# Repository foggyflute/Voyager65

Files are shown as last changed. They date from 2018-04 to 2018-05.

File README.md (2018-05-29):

# Voyager65
Cutting-edge 65% keyboard PCB

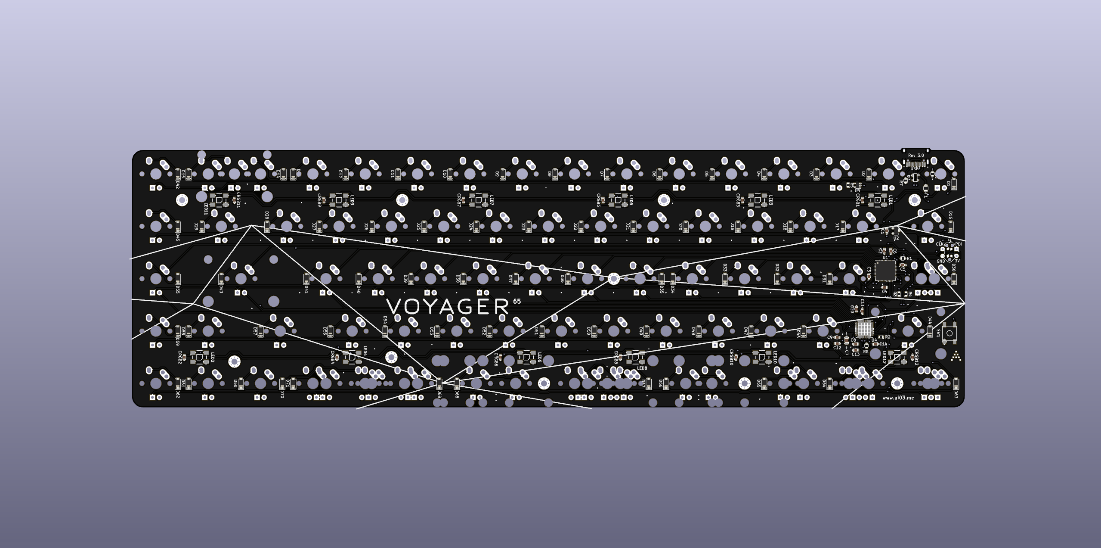
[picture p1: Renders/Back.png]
Frontside Render

[Supported Layouts](http://www.keyboard-layout-editor.com/#/gists/98784f0271c0b4e29edec77185eb883a)

## Features
* Full individual-controllable backlighting via ISSI IS31FL3733
* Atxmega32a4u controller for Keyplus firmware usage
* Overcurrent and ESD protection, along with physically durable design
* Type-C USB connector
* RGB underglow with WS2812B/C chips
* Easy programming via TC2030-IDC header
* Alps and MX compatibility
* **Completely** open-source: All the files you need to make a keyboard with it, design a case/plate for it, or even produce a batch of PCBs for your next GB, are all to be available free.
* The latest technology, some of which is untested or unstable.

## Status
* Prototypes created
* Main switch matrix confirmed functional
* LEDs still untested

## Variants
* Voyager65: This branch. All the features.
* [V65LE](https://github.com/ai03-2725/Voyager65/tree/V65LE): A low-cost, stencil-less solderable variant. Same switch matrix, but with all LEDs removed.
* [V65AE](https://github.com/ai03-2725/Voyager65/tree/V65AE): Alps-specific variant.

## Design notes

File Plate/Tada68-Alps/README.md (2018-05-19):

#WARNING

Alps switches are wide! This means a regular M2 screw WILL NOT FIT between two keys, i.e. between G and H!

To get around this, find M2 screws with head diameters smaller than 3.45mm.

Also, the screwdriver for securing the screw must be less than 1.7mm diameter.

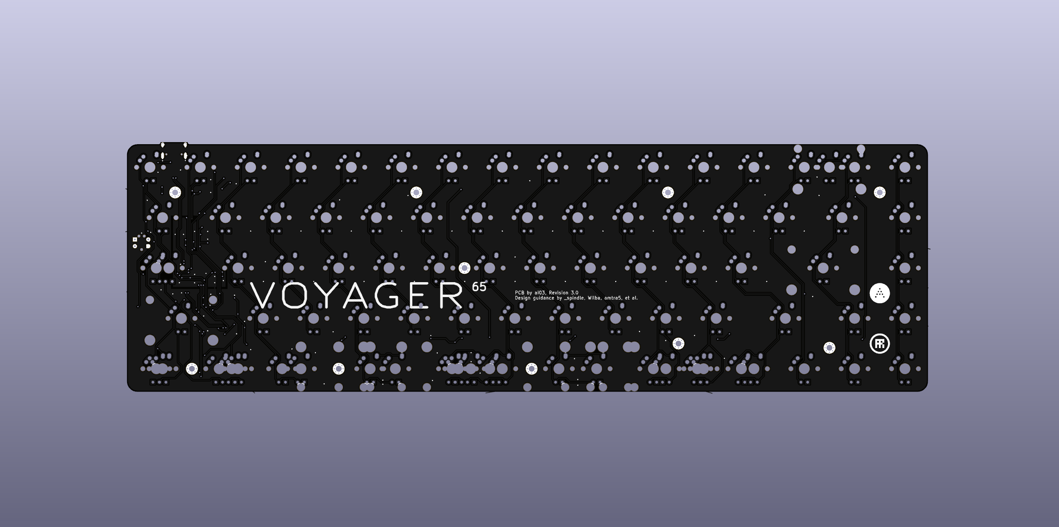
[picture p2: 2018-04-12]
Renders/Front.png

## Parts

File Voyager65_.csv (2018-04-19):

Component | Description | Part | References | Value | Footprint | Quantity Per PCB | Voltage | Wattage | Current Max | Current Hold | Current Trip | Datasheet
1 | Unpolarized capacitor, Ceramic | C_Small | C2 C3 C4 C5 C8 C9 C10 CRGB1 CRGB2 CRGB3 CRGB4 CRGB5 CRGB6 CRGB7 CRGB8 CRGB9 CRGB10 CRGB11 CRGB12 | 0.1u | C_0603 | 19 | 25V
2 | Unpolarized capacitor, Ceramic | C_Small | C11 C12 C13 C14 | 0.47u | C_0603 | 4 | 25V
3 | Unpolarized capacitor, Ceramic | C_Small | C6 | 10u | C_0603 | 1 | 25V
4 | Unpolarized capacitor, Ceramic | C_Small | C1 | 1u | C_0603 | 1 | 25V
5 | Polarised capacitor, Tantalum | CP1_Small | C7 | 22u | C_0805 | 1 | 10V
6 | Diode, General Purpose | D_Small | D1 D2 D3 D4 D5 D6 D7 D8 D9 D10 D11 D12 D13 D14 D15 D16 D17 D18 D19 D20 D21 D22 D23 D24 D25 D26 D27 D28 D29 D30 D31 D32 D33 D34 D35 D36 D37 D38 D39 D40 D41 D42 D43 D44 D45 D46 D47 D48 D49 D50 D51 D52 D53 D54 D55 D56 D57 D58 D59 D60 D61 D62 D63 D64 D65 D66 D67 D68 D69 D70 D71 | D_Small | D_SOD-123 | 71 | 50V or higher |  | 1A
7 | Resettable Fuse (Polyfuse) | Polyfuse_Small | F1 | 500mA | R_0805 | 1 | 10V or higher |  |  | 500mA | 1A
8 | RGB LED with integrated controller | WS2812B | LED1 LED2 LED3 LED4 LED5 LED6 LED7 LED8 LED9 LED10 LED11 LED12 | WS2812B | WS2812B | 12
9 | Resistor, generic | R_Small | R2 | 100k | R_0603 | 1 |  | 1/10W or higher
10 | Resistor, generic | R_Small | R1 | 10k | R_0603 | 1 |  | 1/10W or higher
11 | Resistor, generic | R_Small | R3 R4 | 1k | R_0603 | 2 |  | 1/10W or higher
12 | Resistor, generic | R_Small | R8 | 20k | R_0603 | 1 |  | 1/10W or higher
13 | Resistor, generic | R_Small | R6 R7 | 5.1k | R_0603 | 2 |  | 1/10W or higher
14 | Resistor, generic | R_Small | R5 | 470 | R_0603 | 1 |  | 1/10W or higher
15 | Push switch, 5.2mm wide, 1.5mm tall | SW_PUSH | SW1 | SW_PUSH | SKQG-1155865 | 1
16 | Non-Inverting IC Buffer 74LVC1G34 | 74LVC1G34 | U5 | 74LVC1G34 | SOT-353_SC-70-5 | 1 | 5.5V |  |  |  |  | https://www.diodes.com/assets/Datasheets/74LVC1G34.pdf
17 | TQFP44, 16k Flash, 4k Boot, 2k SRAM, 1k EEPROM, JTAG, USB | ATXMEGA32A4U-AU | U1 | ATXMEGA32A4U-MH | QFN-44-1EP_7x7mm_Pitch0.5mm | 1 |  |  |  |  |  | http://www.atmel.com/Images/Atmel-8387-8-and16-bit-AVR-Microcontroller-XMEGA-A4U_Datasheet.pdf
18 | LED Matrix Driver IS31FL3733 | IS31FL3733 | U4 | IS31FL3733-QFLS4-TR | QFN-48-1EP_6x6mm_Pitch0.4mm | 1 |  |  |  |  |  | http://www.issi.com/WW/pdf/31FL3733.pdf
19 | 250mA Low Quiscent Current LDO, 3.0V output, SOT-23 | MCP1700-3002E_SOT23 | U2 | MCP1700T-3002E/TT | SOT-23 | 1 |  |  |  |  |  | http://ww1.microchip.com/downloads/en/DeviceDoc/20001826C.pdf
20 | ESD Protection Diode IC | PRTR5V0U2X | U3 | PRTR5V0U2X | SOT143B | 1 |  |  |  |  |  | https://assets.nexperia.com/documents/data-sheet/PRTR5V0U2X.pdf
21 | USB Type-C Connector HRO-TYPE-C-31-M-12 | HRO-TYPE-C-31-M-12 | USB1 | HRO-TYPE-C-31-M-12 | HRO-TYPE-C-31-M-12 | 1 |  |  |  |  |  | https://datasheet.lcsc.com/szlcsc/TYPE-C-31-M-12-Female-head-socket-16P-SMD_C165948.pdf
Component Groups: | 21
Component Count: | 125
Fitted Components: | 125
Number of PCBs: | 1
Total components: | 125
Schematic Version:
Schematic Date:
BoM Date: | 4/17/2018 20:48
Schematic Source: | C:/Users/Ryota/Documents/GitHub/Voyager65/Voyager65.sch
KiCad Version: | Eeschema 4.0.7

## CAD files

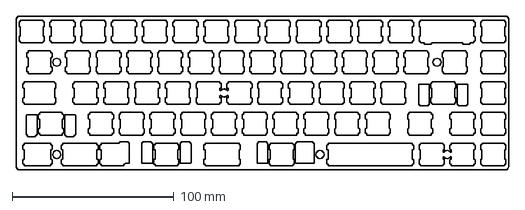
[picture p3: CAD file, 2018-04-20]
Plate/Source/Tada68-MX.dxf
304.8 x 95.3 mm

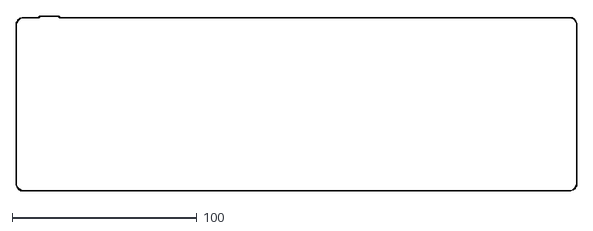
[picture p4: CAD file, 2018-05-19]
DXF/Voyager65-Edge.Cuts.dxf
303.4 x 94.6

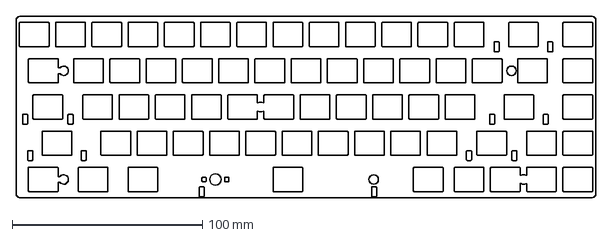
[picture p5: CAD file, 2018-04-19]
Plate/Source/Tada68-Alps.dxf
304.8 x 95.3 mm

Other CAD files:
DXF/Voyager65-F.Fab.dxf
DXF/Voyager65-B.Mask.dxf
DXF/Voyager65-B.Paste.dxf
DXF/Voyager65-B.SilkS.dxf
DXF/Voyager65-F.Mask.dxf
DXF/Voyager65-F.Paste.dxf
DXF/Voyager65-F.SilkS.dxf

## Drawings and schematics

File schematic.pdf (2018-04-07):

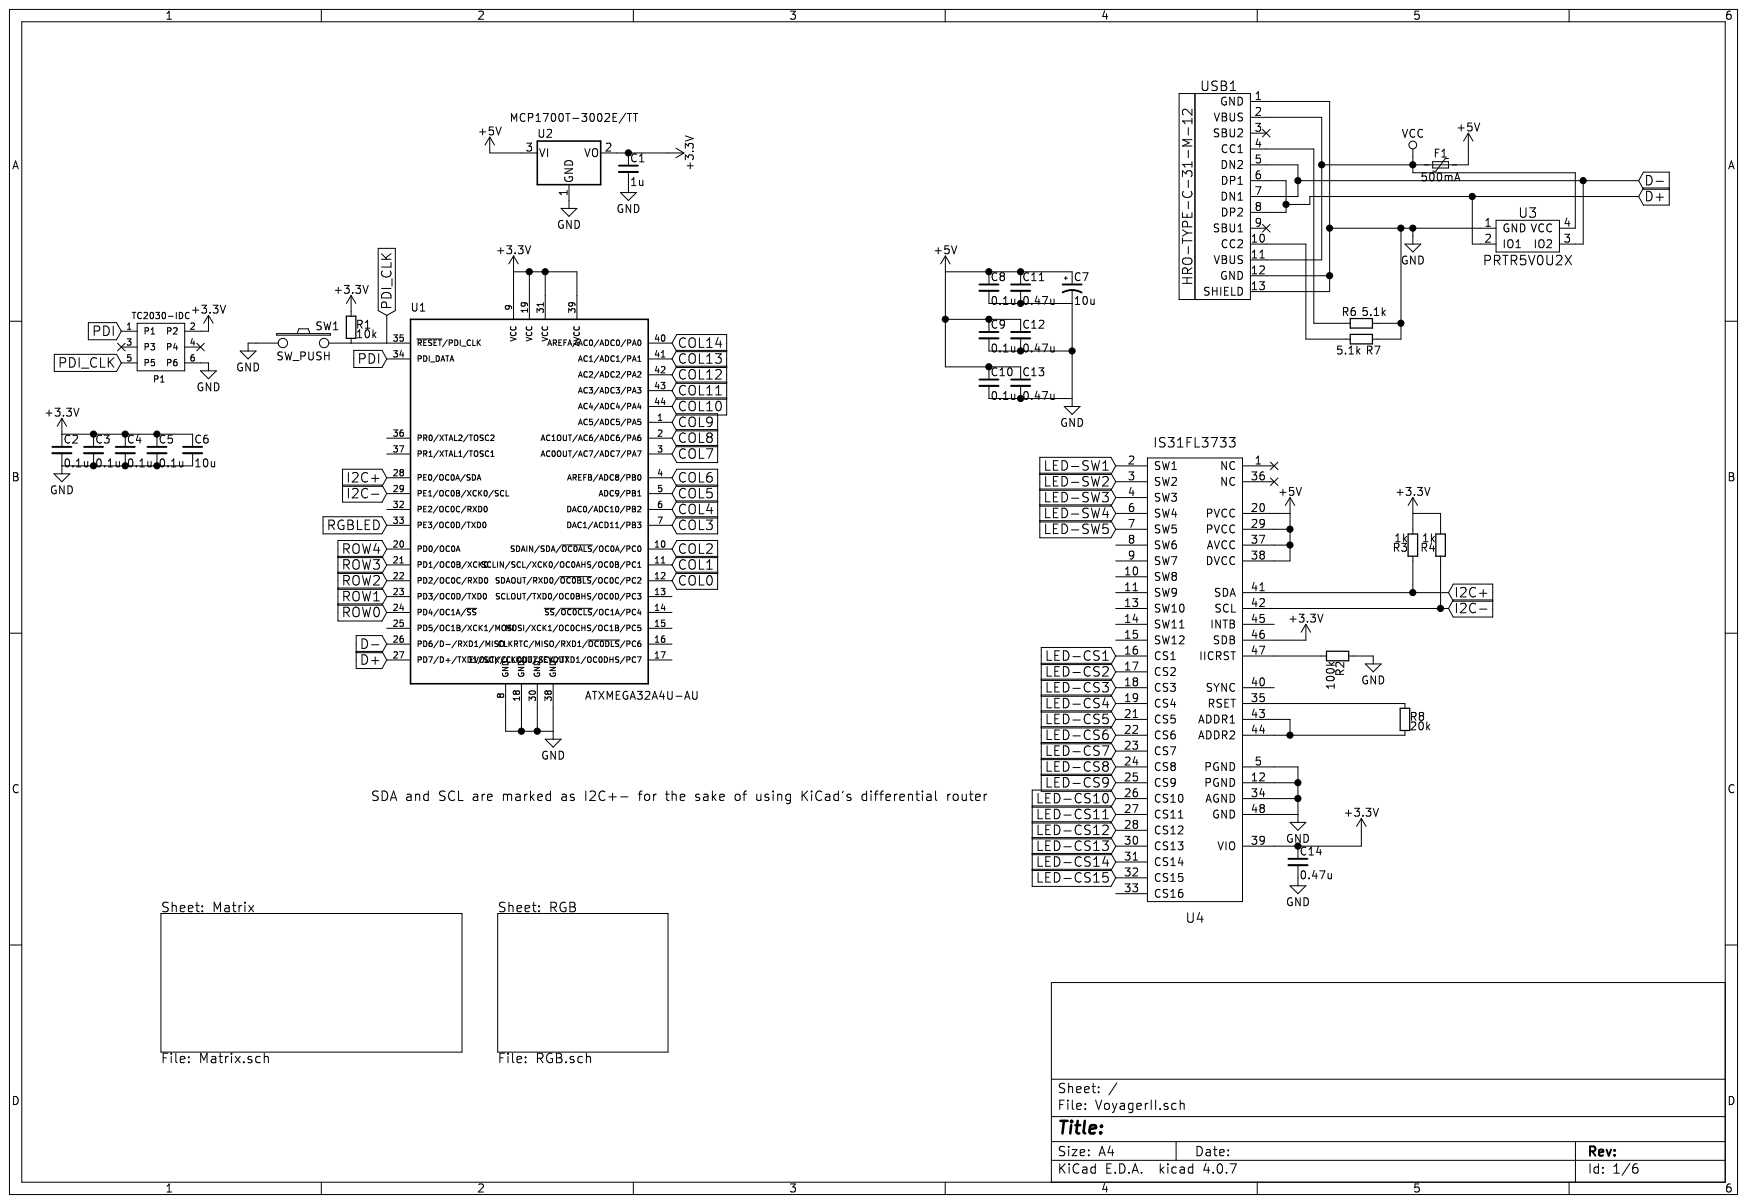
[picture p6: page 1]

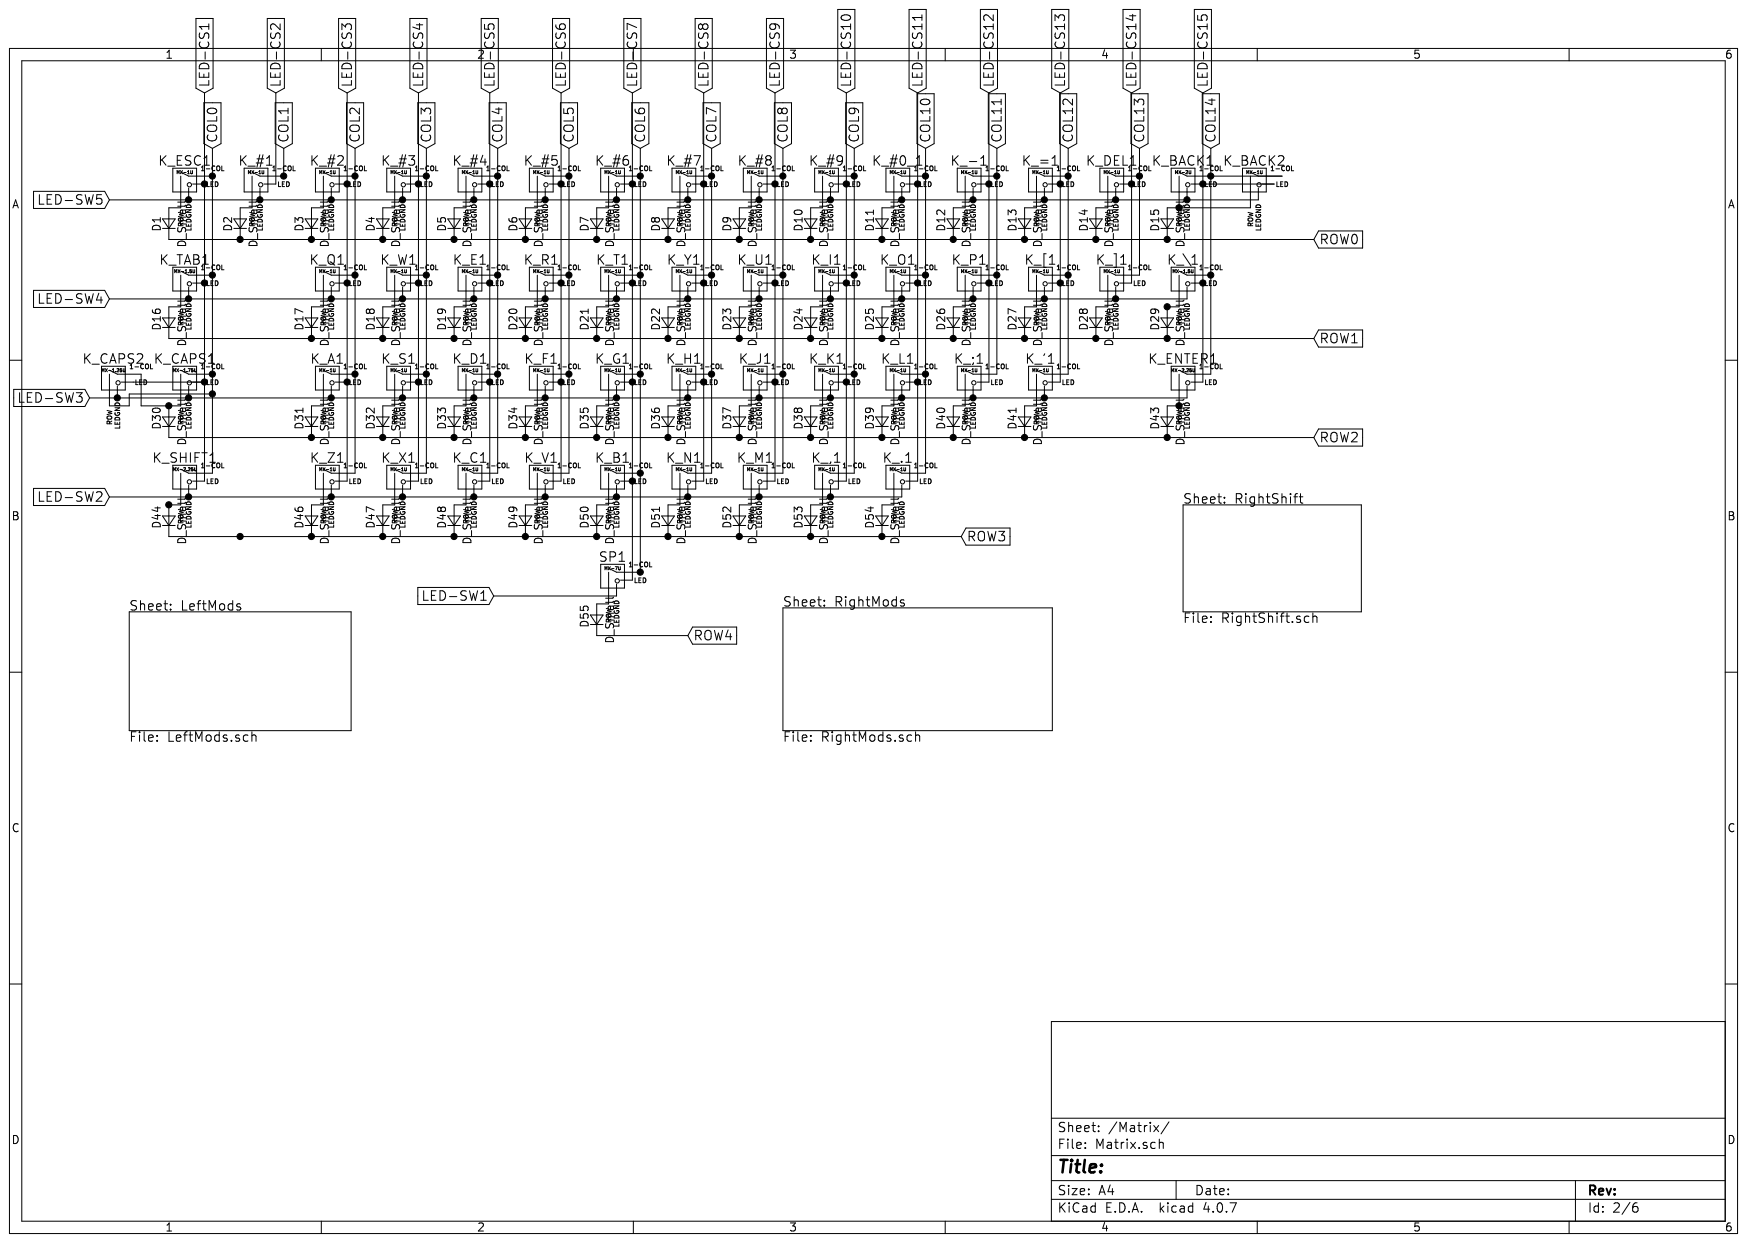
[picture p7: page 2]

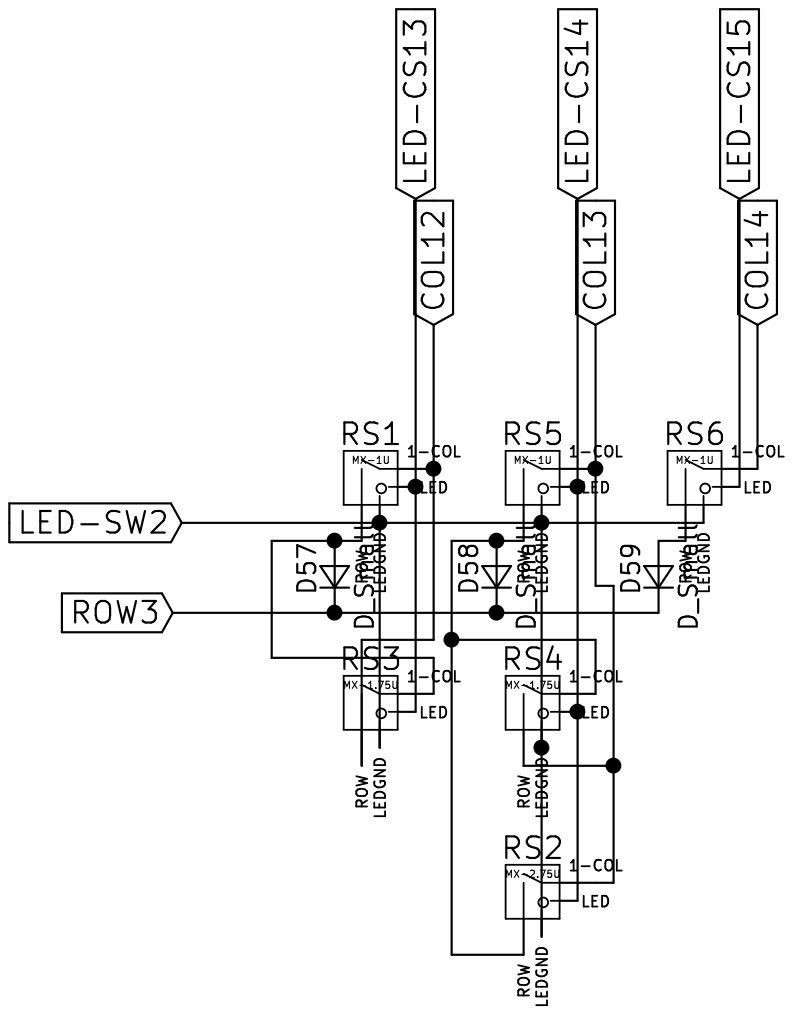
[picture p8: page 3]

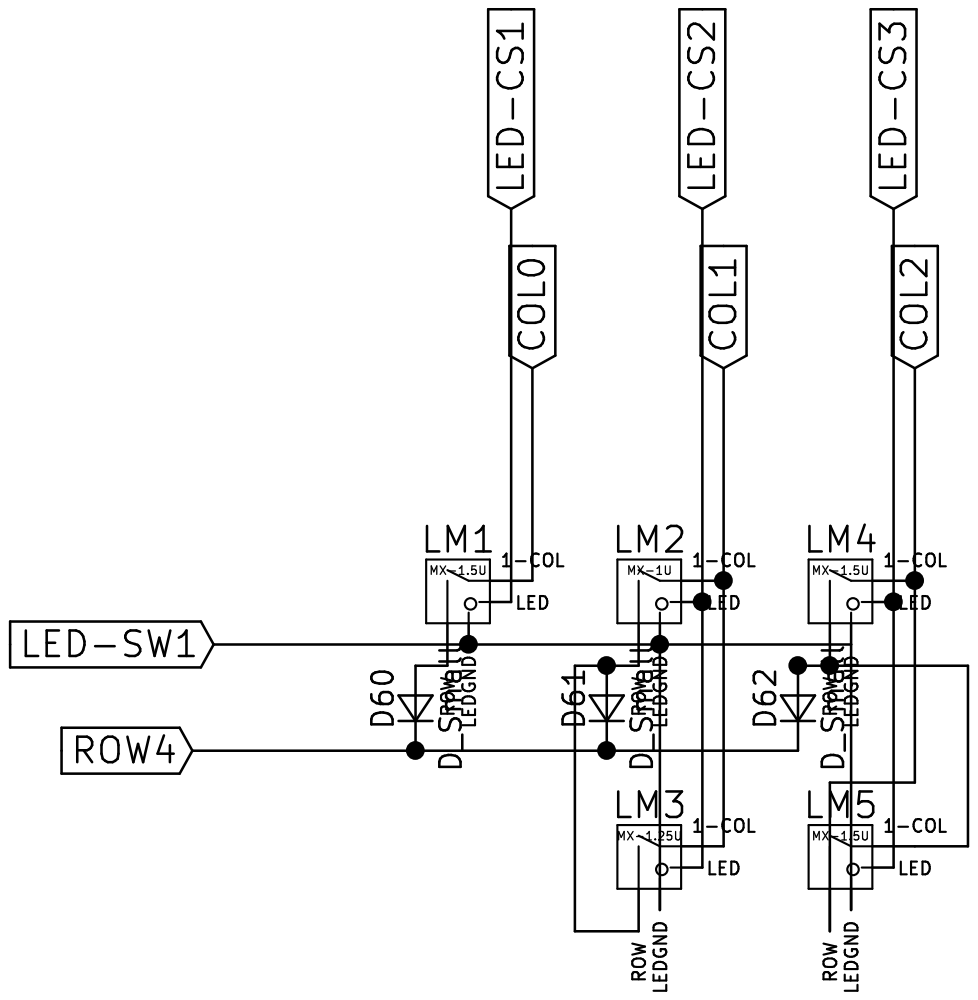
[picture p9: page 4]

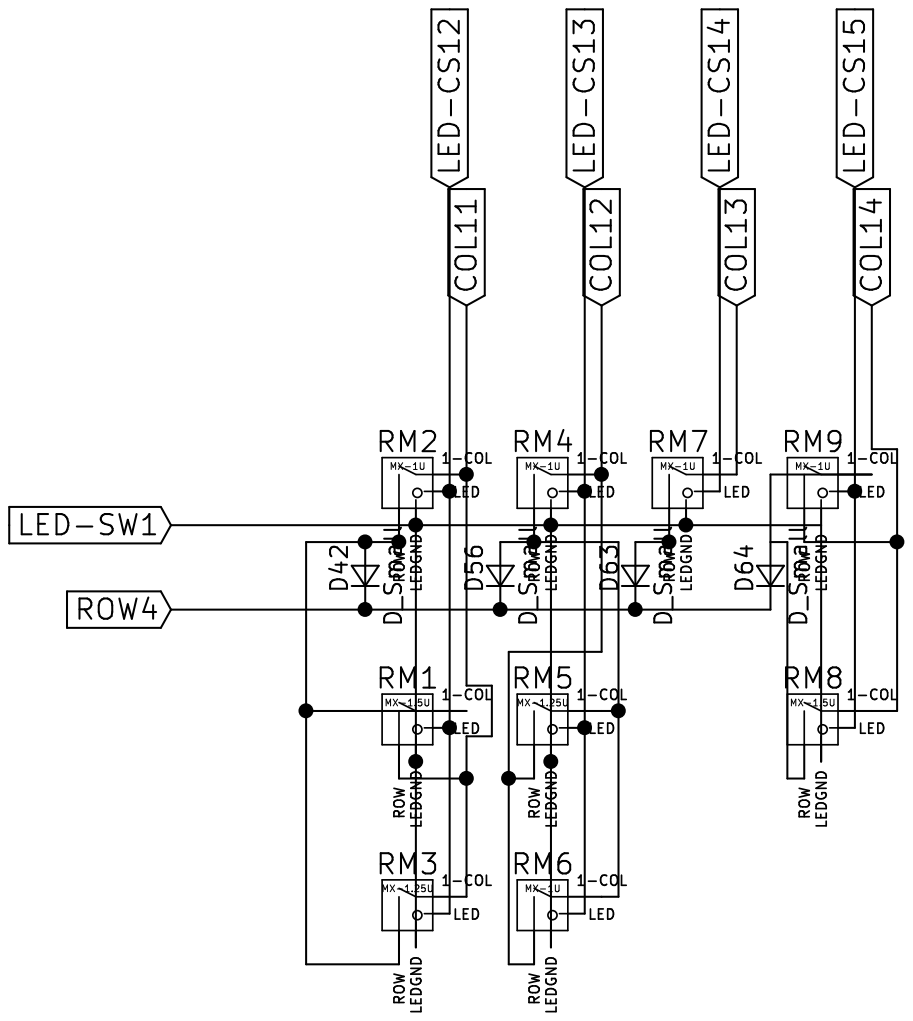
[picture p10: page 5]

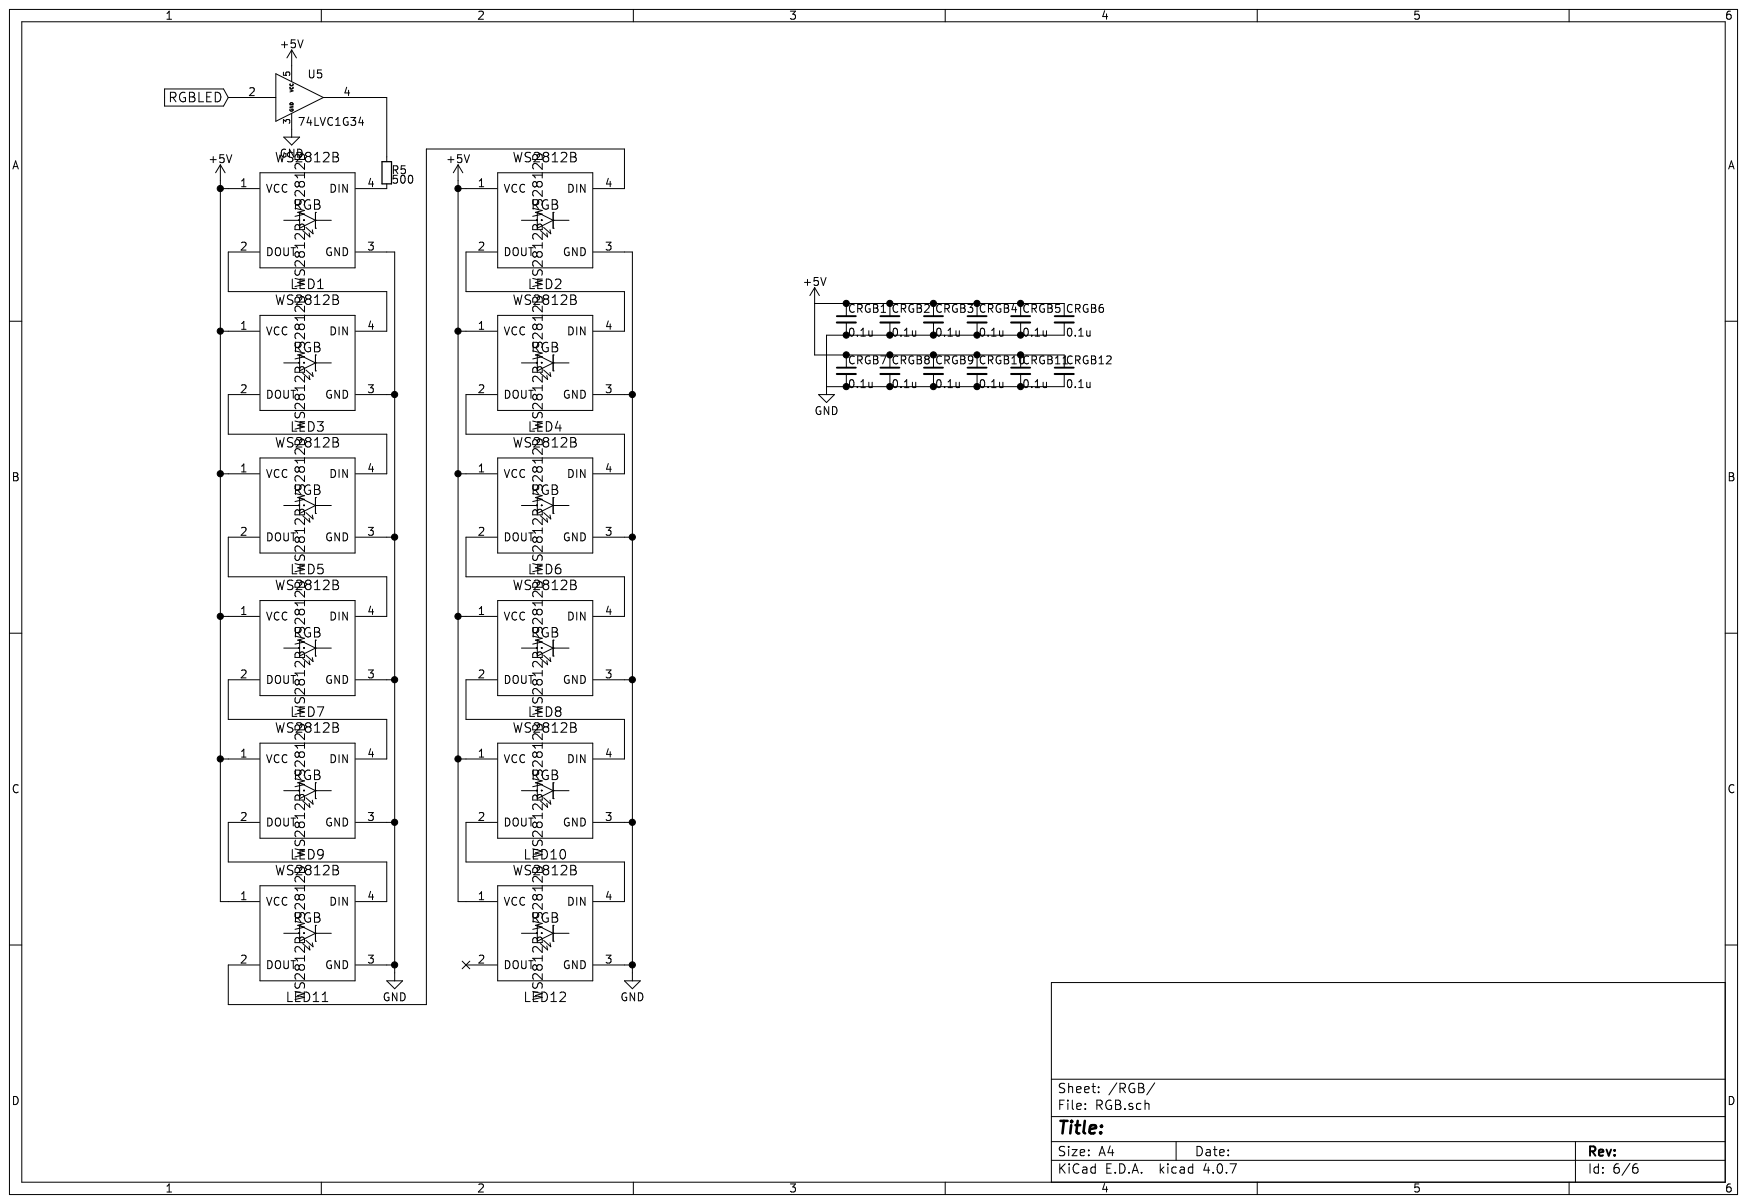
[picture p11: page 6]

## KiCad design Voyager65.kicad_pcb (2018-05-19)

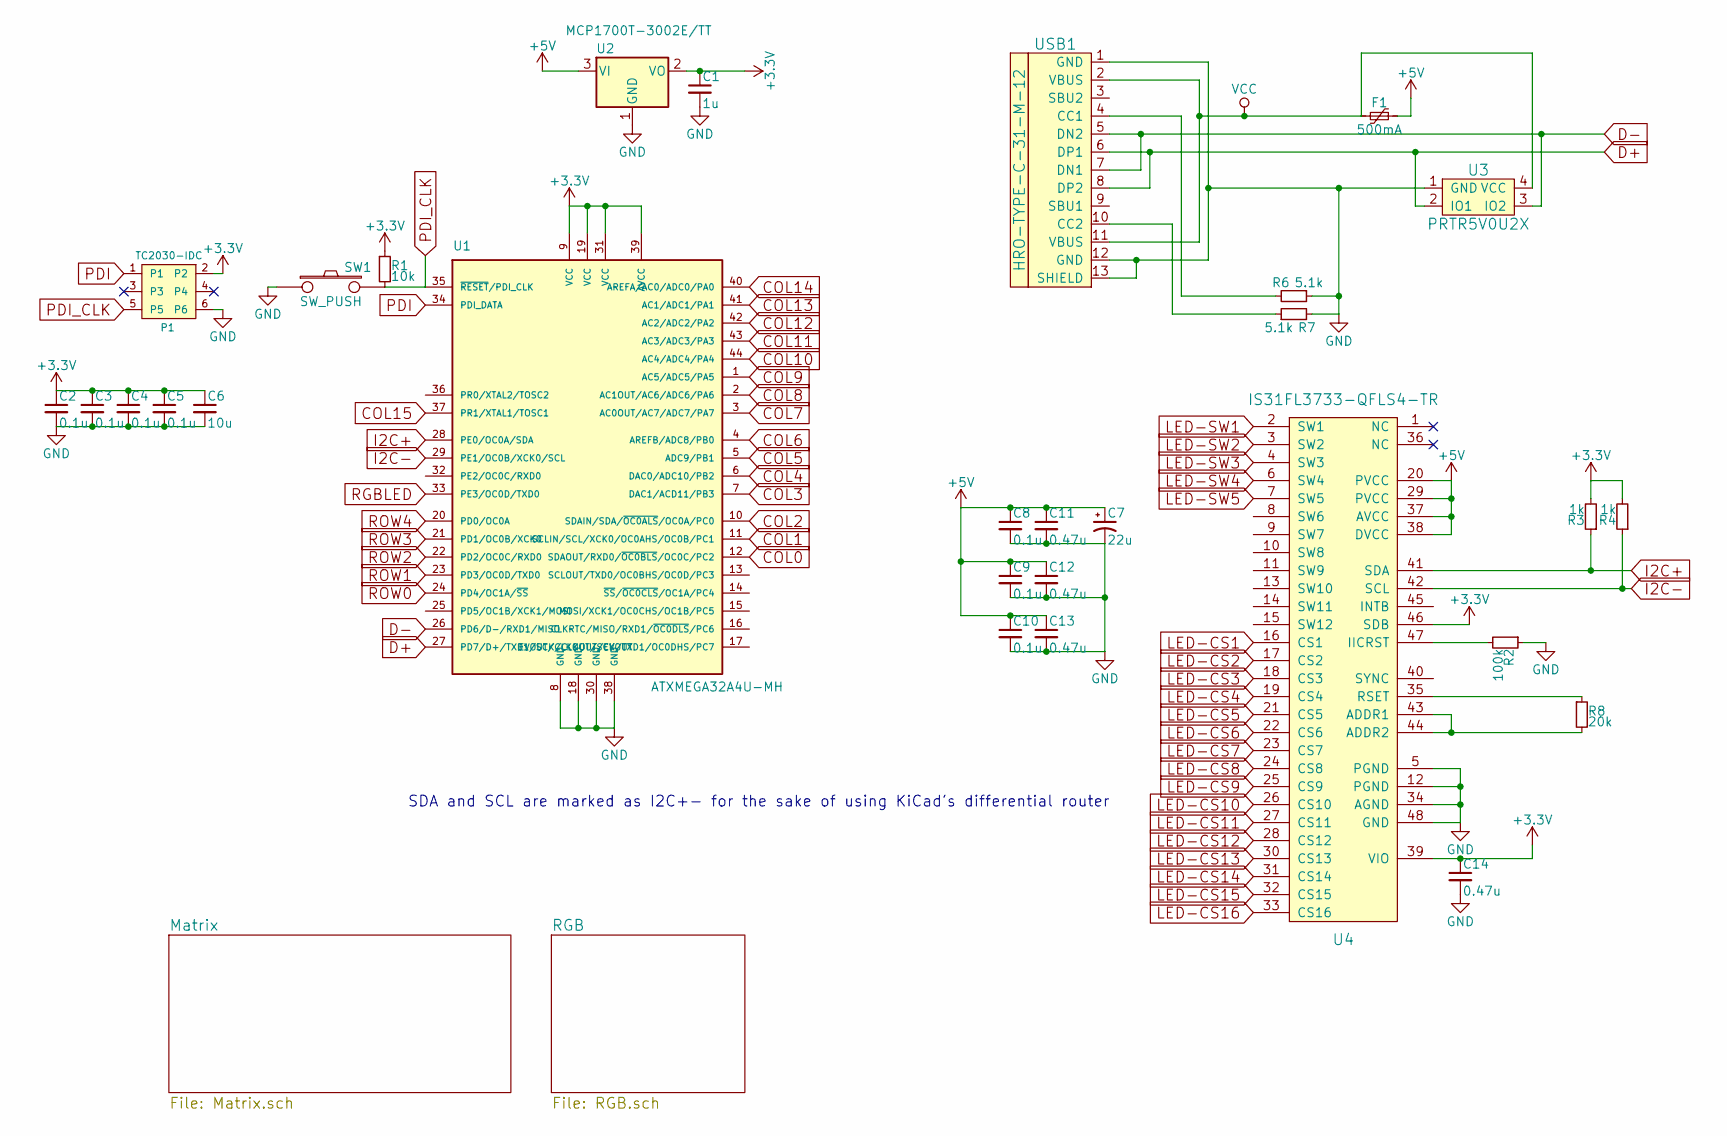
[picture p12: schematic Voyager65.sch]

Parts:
C1: 1u; C_0603
C2, C3, C4, C5, C8, C9, C10: 0.1u; C_0603
C6: 10u; C_0603
C7: 22u; C_0805; Voltage 10V
C11, C12, C13, C14: 0.47u; C_0603
F1: 500mA; R_0805
P1: TC2030-IDC; TC2030-NL_SMALL_AND_IDC_PDI
R1: 10k; R_0603
R2: 100k; R_0603
R3, R4: 1k; R_0603
R6, R7: 5.1k; R_0603
R8: 20k; R_0603
SW1: SW_PUSH; SKQG-1155865
U1: ATXMEGA32A4U-MH; QFN-44-1EP_7x7mm_Pitch0.5mm
U2: MCP1700T-3002E/TT; SOT-23
U3: PRTR5V0U2X; SOT143B
U4: IS31FL3733-QFLS4-TR; QFN-48-1EP_6x6mm_Pitch0.4mm
USB1: HRO-TYPE-C-31-M-12

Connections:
+3V3: C1.1, C2.1, C3.1, C4.1, C5.1, C6.1, C14.1, P1.2, R1.1, R3.2, R4.2, U1.9 (VCC), U1.19 (VCC), U1.31 (VCC), U1.39 (AVCC), U2.2 (VO), U4.39 (VIO), U4.46 (SDB)
+5V: C7.1, C8.1, C9.1, C10.1, C11.1, C12.1, C13.1, F1.1, U2.3 (VI), U4.20 (PVCC), U4.29 (PVCC), U4.37 (AVCC), U4.38 (DVCC); also elsewhere on the board
COL0: U1.12 (SDAOUT/RXD0/~OC0BLS~/OC0C/PC2); also elsewhere on the board
COL1: U1.11 (SCLIN/SCL/XCK0/OC0AHS/OC0B/PC1); also elsewhere on the board
COL2: U1.10 (SDAIN/SDA/~OC0ALS~/OC0A/PC0); also elsewhere on the board
COL3: U1.7 (DAC1/ACD11/PB3); also elsewhere on the board
COL4: U1.6 (DAC0/ADC10/PB2); also elsewhere on the board
COL5: U1.5 (ADC9/PB1); also elsewhere on the board
COL6: U1.4 (AREFB/ADC8/PB0); also elsewhere on the board
COL7: U1.3 (AC0OUT/AC7/ADC7/PA7); also elsewhere on the board
COL8: U1.2 (AC1OUT/AC6/ADC6/PA6); also elsewhere on the board
COL9: U1.1 (AC5/ADC5/PA5); also elsewhere on the board
COL10: U1.44 (AC4/ADC4/PA4); also elsewhere on the board
COL11: U1.43 (AC3/ADC3/PA3); also elsewhere on the board
COL12: U1.42 (AC2/ADC2/PA2); also elsewhere on the board
COL13: U1.41 (AC1/ADC1/PA1); also elsewhere on the board
COL14: U1.40 (AREFA/AC0/ADC0/PA0); also elsewhere on the board
COL15: U1.37 (PR1/XTAL1/TOSC1); also elsewhere on the board
D+: U1.27 (PD7/D+/TXD1/SCK/CLKOUT/EVOUT), U3.2 (IO1), USB1.6 (DP1), USB1.8 (DP2)
D-: U1.26 (PD6/D-/RXD1/MISO), U3.3 (IO2), USB1.5 (DN2), USB1.7 (DN1)
GND: C1.2, C2.2, C3.2, C4.2, C5.2, C6.2, C7.2, C8.2, C9.2, C10.2, C11.2, C12.2, C13.2, C14.2, P1.6, R2.1, R6.1, R7.2, SW1.1, U1.8 (GND), U1.18 (GND), U1.30 (GND), U1.38 (GND), U2.1 (GND), U3.1 (GND), U4.5 (PGND), U4.12 (PGND), U4.34 (AGND), U4.48 (GND), USB1.1 (GND), USB1.12 (GND), USB1.13 (SHIELD); also elsewhere on the board
I2C+: R3.1, U1.28 (PE0/OC0A/SDA), U4.41 (SDA)
I2C-: R4.1, U1.29 (PE1/OC0B/XCK0/SCL), U4.42 (SCL)
LED-CS1: U4.16 (CS1); also elsewhere on the board
LED-CS2: U4.17 (CS2); also elsewhere on the board
LED-CS3: U4.18 (CS3); also elsewhere on the board
LED-CS4: U4.19 (CS4); also elsewhere on the board
LED-CS5: U4.21 (CS5); also elsewhere on the board
LED-CS6: U4.22 (CS6); also elsewhere on the board
LED-CS7: U4.23 (CS7); also elsewhere on the board
LED-CS8: U4.24 (CS8); also elsewhere on the board
LED-CS9: U4.25 (CS9); also elsewhere on the board
LED-CS10: U4.26 (CS10); also elsewhere on the board
LED-CS11: U4.27 (CS11); also elsewhere on the board
LED-CS12: U4.28 (CS12); also elsewhere on the board
LED-CS13: U4.30 (CS13); also elsewhere on the board
LED-CS14: U4.31 (CS14); also elsewhere on the board
LED-CS15: U4.32 (CS15); also elsewhere on the board
LED-CS16: U4.33 (CS16); also elsewhere on the board
LED-SW1: U4.2 (SW1); also elsewhere on the board
LED-SW2: U4.3 (SW2); also elsewhere on the board
LED-SW3: U4.4 (SW3); also elsewhere on the board
LED-SW4: U4.6 (SW4); also elsewhere on the board
LED-SW5: U4.7 (SW5); also elsewhere on the board
unnamed: R2.2, U4.47 (IICRST)
unnamed: R6.2, USB1.4 (CC1)
unnamed: R7.1, USB1.10 (CC2)
unnamed: R8.1, U4.35 (RSET)
unnamed: R8.2, U4.43 (ADDR1), U4.44 (ADDR2)
PDI: P1.1, U1.34 (PDI_DATA)
PDI_CLK: P1.5, R1.2, SW1.2, U1.35 (~RESET~/PDI_CLK)
RGBLED: U1.33 (PE3/OC0D/TXD0); also elsewhere on the board
ROW0: U1.24 (PD4/OC1A/~SS~); also elsewhere on the board
ROW1: U1.23 (PD3/OC0D/TXD0); also elsewhere on the board
ROW2: U1.22 (PD2/OC0C/RXD0); also elsewhere on the board
ROW3: U1.21 (PD1/OC0B/XCK0); also elsewhere on the board
ROW4: U1.20 (PD0/OC0A); also elsewhere on the board
VCC: F1.2, U3.4 (VCC), USB1.2 (VBUS), USB1.11 (VBUS)

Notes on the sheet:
SDA and SCL are marked as I2C+- for the sake of using KiCad's differential router

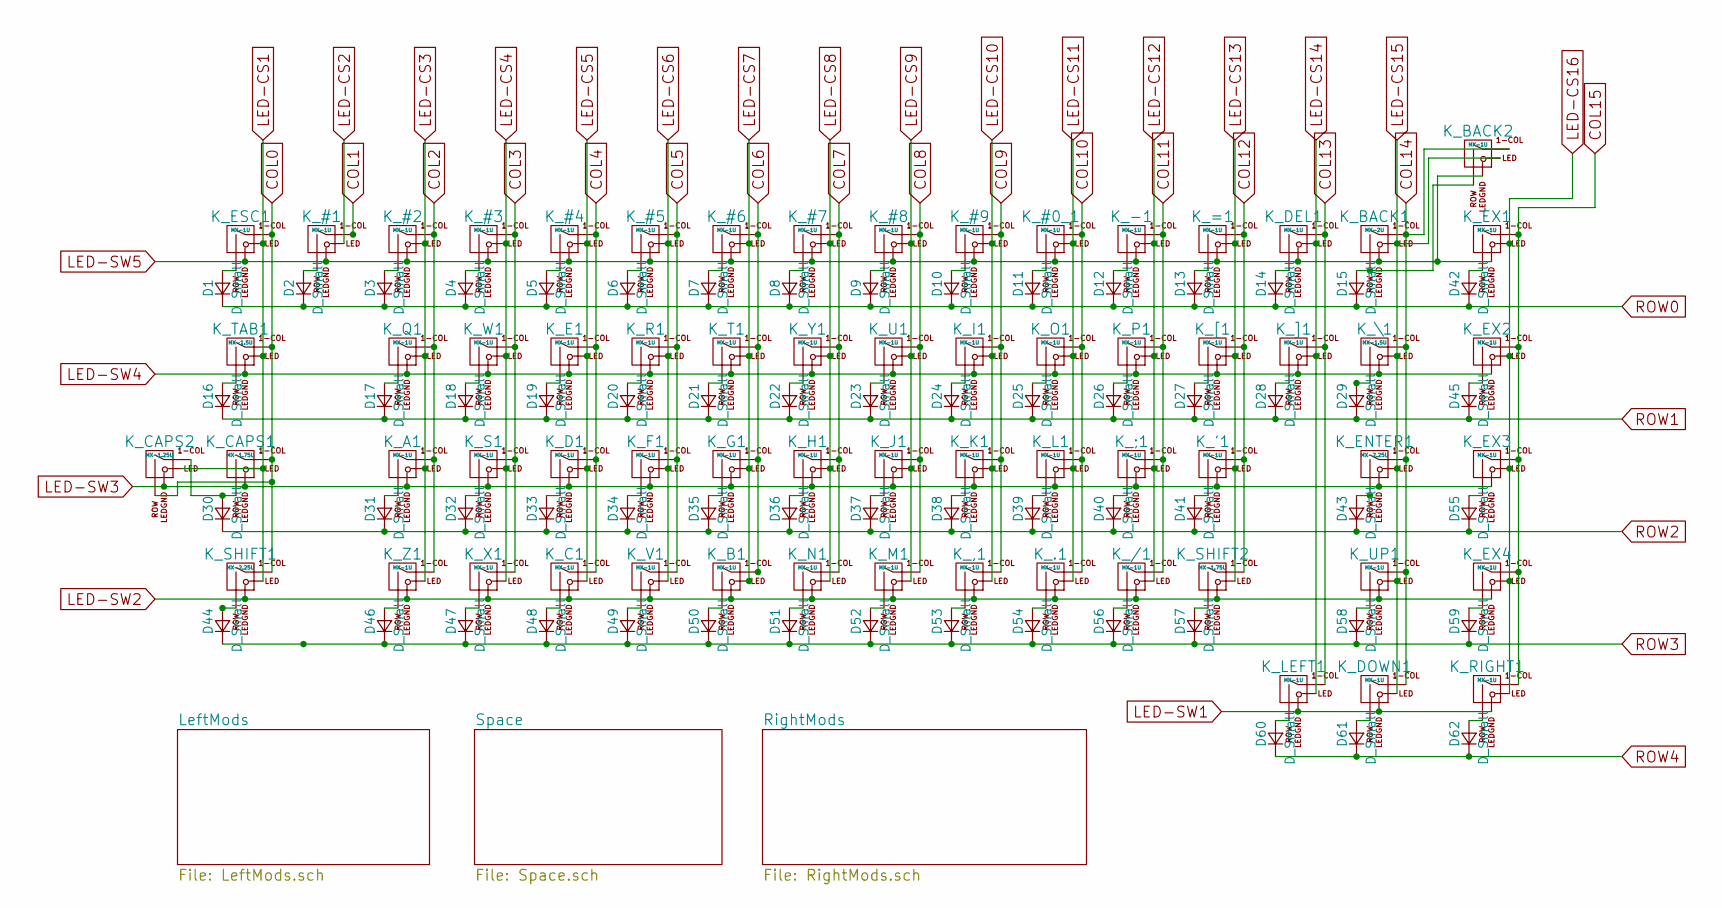
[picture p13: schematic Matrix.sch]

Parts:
D1, D2, D3, D4, D5, D6, D7, D8, D9, D10, D11, D12, D13, D14, D15, D16, D17, D18, D19, D20, D21, D22, D23, D24, D25, D26, D27, D28, D29, D30, D31, D32, D33, D34, D35, D36, D37, D38, D39, D40, D41, D42, D43, D44, D45, D46, D47, D48, D49, D50, D51, D52, D53, D54, D55, D56, D57, D58, D59, D60, D61, D62: D_Small; D_SOD-123
K_#0_1, K_#1, K_#2, K_#3, K_#4, K_#5, K_#6, K_#7, K_#8, K_#9: MX-1U
K_'1: MX-1U
K_,1: MX-1U
K_-1: MX-1U
K_.1: MX-1U
K_/1: MX-1U
K_;1: MX-1U
K_=1: MX-1U
K_A1: MX-1U
K_B1: MX-1U
K_BACK1: MX-2U
K_BACK2: MX-1U
K_C1: MX-1U
K_CAPS1: MX-1.75U
K_CAPS2: MX-1.25U; MX-1.25U-FLIPPED
K_D1: MX-1U
K_DEL1: MX-1U
K_DOWN1: MX-1U
K_E1: MX-1U
K_ENTER1: MX-2.25U
K_ESC1: MX-1U
K_EX1, K_EX2, K_EX3, K_EX4: MX-1U
K_F1: MX-1U
K_G1: MX-1U
K_H1: MX-1U
K_I1: MX-1U
K_J1: MX-1U
K_K1: MX-1U
K_L1: MX-1U
K_LEFT1: MX-1U
K_M1: MX-1U
K_N1: MX-1U
K_O1: MX-1U
K_P1: MX-1U
K_Q1: MX-1U
K_R1: MX-1U
K_RIGHT1: MX-1U
K_S1: MX-1U
K_SHIFT1: MX-2.25U
K_SHIFT2: MX-1.75U
K_T1: MX-1U
K_TAB1: MX-1.5U
K_U1: MX-1U
K_UP1: MX-1U
K_V1: MX-1U
K_W1: MX-1U
K_X1: MX-1U
K_Y1: MX-1U
K_Z1: MX-1U
K_[1: MX-1U
K_\1: MX-1.5U
K_]1: MX-1U

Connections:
COL0: K_CAPS1.1 (COL), K_CAPS2.2 (ROW), K_ESC1.1 (COL), K_SHIFT1.1 (COL), K_TAB1.1 (COL); also elsewhere on the board
COL1: K_#1.1 (COL); also elsewhere on the board
COL2: K_#2.1 (COL), K_A1.1 (COL), K_Q1.1 (COL), K_Z1.1 (COL); also elsewhere on the board
COL3: K_#3.1 (COL), K_S1.1 (COL), K_W1.1 (COL), K_X1.1 (COL); also elsewhere on the board
COL4: K_#4.1 (COL), K_C1.1 (COL), K_D1.1 (COL), K_E1.1 (COL); also elsewhere on the board
COL5: K_#5.1 (COL), K_F1.1 (COL), K_R1.1 (COL), K_V1.1 (COL); also elsewhere on the board
COL6: K_#6.1 (COL), K_B1.1 (COL), K_G1.1 (COL), K_T1.1 (COL); also elsewhere on the board
COL7: K_#7.1 (COL), K_H1.1 (COL), K_N1.1 (COL), K_Y1.1 (COL); also elsewhere on the board
COL8: K_#8.1 (COL), K_J1.1 (COL), K_M1.1 (COL), K_U1.1 (COL); also elsewhere on the board
COL9: K_#9.1 (COL), K_,1.1 (COL), K_I1.1 (COL), K_K1.1 (COL); also elsewhere on the board
COL10: K_#0_1.1 (COL), K_.1.1 (COL), K_L1.1 (COL), K_O1.1 (COL); also elsewhere on the board
COL11: K_-1.1 (COL), K_/1.1 (COL), K_;1.1 (COL), K_P1.1 (COL); also elsewhere on the board
COL12: K_'1.1 (COL), K_=1.1 (COL), K_SHIFT2.1 (COL), K_[1.1 (COL); also elsewhere on the board
COL13: K_DEL1.1 (COL), K_LEFT1.1 (COL), K_]1.1 (COL); also elsewhere on the board
COL14: K_BACK1.1 (COL), K_BACK2.1 (COL), K_DOWN1.1 (COL), K_ENTER1.1 (COL), K_UP1.1 (COL), K_\1.1 (COL); also elsewhere on the board
COL15: K_EX1.1 (COL), K_EX2.1 (COL), K_EX3.1 (COL), K_EX4.1 (COL), K_RIGHT1.1 (COL); also elsewhere on the board
LED-CS1: K_CAPS1.3 (LED), K_CAPS2.3 (LED), K_ESC1.3 (LED), K_SHIFT1.3 (LED), K_TAB1.3 (LED); also elsewhere on the board
LED-CS2: K_#1.3 (LED); also elsewhere on the board
LED-CS3: K_#2.3 (LED), K_A1.3 (LED), K_Q1.3 (LED), K_Z1.3 (LED); also elsewhere on the board
LED-CS4: K_#3.3 (LED), K_S1.3 (LED), K_W1.3 (LED), K_X1.3 (LED); also elsewhere on the board
LED-CS5: K_#4.3 (LED), K_C1.3 (LED), K_D1.3 (LED), K_E1.3 (LED); also elsewhere on the board
LED-CS6: K_#5.3 (LED), K_F1.3 (LED), K_R1.3 (LED), K_V1.3 (LED); also elsewhere on the board
LED-CS7: K_#6.3 (LED), K_B1.3 (LED), K_G1.3 (LED), K_T1.3 (LED); also elsewhere on the board
LED-CS8: K_#7.3 (LED), K_H1.3 (LED), K_N1.3 (LED), K_Y1.3 (LED); also elsewhere on the board
LED-CS9: K_#8.3 (LED), K_J1.3 (LED), K_M1.3 (LED), K_U1.3 (LED); also elsewhere on the board
LED-CS10: K_#9.3 (LED), K_,1.3 (LED), K_I1.3 (LED), K_K1.3 (LED); also elsewhere on the board
LED-CS11: K_#0_1.3 (LED), K_.1.3 (LED), K_L1.3 (LED), K_O1.3 (LED); also elsewhere on the board
LED-CS12: K_-1.3 (LED), K_/1.3 (LED), K_;1.3 (LED), K_P1.3 (LED); also elsewhere on the board
LED-CS13: K_'1.3 (LED), K_=1.3 (LED), K_SHIFT2.3 (LED), K_[1.3 (LED); also elsewhere on the board
LED-CS14: K_DEL1.3 (LED), K_LEFT1.3 (LED), K_]1.3 (LED); also elsewhere on the board
LED-CS15: K_BACK1.3 (LED), K_BACK2.3 (LED), K_DOWN1.3 (LED), K_ENTER1.3 (LED), K_UP1.3 (LED), K_\1.3 (LED); also elsewhere on the board
LED-CS16: K_EX1.3 (LED), K_EX2.3 (LED), K_EX3.3 (LED), K_EX4.3 (LED), K_RIGHT1.3 (LED); also elsewhere on the board
LED-SW1: K_DOWN1.4 (LEDGND), K_LEFT1.4 (LEDGND), K_RIGHT1.4 (LEDGND); also elsewhere on the board
LED-SW2: K_,1.4 (LEDGND), K_.1.4 (LEDGND), K_/1.4 (LEDGND), K_B1.4 (LEDGND), K_C1.4 (LEDGND), K_EX4.4 (LEDGND), K_M1.4 (LEDGND), K_N1.4 (LEDGND), K_SHIFT1.4 (LEDGND), K_SHIFT2.4 (LEDGND), K_UP1.4 (LEDGND), K_V1.4 (LEDGND), K_X1.4 (LEDGND), K_Z1.4 (LEDGND); also elsewhere on the board
LED-SW3: K_'1.4 (LEDGND), K_;1.4 (LEDGND), K_A1.4 (LEDGND), K_CAPS1.4 (LEDGND), K_CAPS2.4 (LEDGND), K_D1.4 (LEDGND), K_ENTER1.4 (LEDGND), K_EX3.4 (LEDGND), K_F1.4 (LEDGND), K_G1.4 (LEDGND), K_H1.4 (LEDGND), K_J1.4 (LEDGND), K_K1.4 (LEDGND), K_L1.4 (LEDGND), K_S1.4 (LEDGND); also elsewhere on the board
LED-SW4: K_E1.4 (LEDGND), K_EX2.4 (LEDGND), K_I1.4 (LEDGND), K_O1.4 (LEDGND), K_P1.4 (LEDGND), K_Q1.4 (LEDGND), K_R1.4 (LEDGND), K_T1.4 (LEDGND), K_TAB1.4 (LEDGND), K_U1.4 (LEDGND), K_W1.4 (LEDGND), K_Y1.4 (LEDGND), K_[1.4 (LEDGND), K_\1.4 (LEDGND), K_]1.4 (LEDGND); also elsewhere on the board
LED-SW5: K_#0_1.4 (LEDGND), K_#1.4 (LEDGND), K_#2.4 (LEDGND), K_#3.4 (LEDGND), K_#4.4 (LEDGND), K_#5.4 (LEDGND), K_#6.4 (LEDGND), K_#7.4 (LEDGND), K_#8.4 (LEDGND), K_#9.4 (LEDGND), K_-1.4 (LEDGND), K_=1.4 (LEDGND), K_BACK1.4 (LEDGND), K_BACK2.4 (LEDGND), K_DEL1.4 (LEDGND), K_ESC1.4 (LEDGND), K_EX1.4 (LEDGND); also elsewhere on the board
unnamed: D1.2 (A), K_ESC1.2 (ROW)
unnamed: D2.2 (A), K_#1.2 (ROW)
unnamed: D3.2 (A), K_#2.2 (ROW)
unnamed: D4.2 (A), K_#3.2 (ROW)
unnamed: D5.2 (A), K_#4.2 (ROW)
unnamed: D6.2 (A), K_#5.2 (ROW)
unnamed: D7.2 (A), K_#6.2 (ROW)
unnamed: D8.2 (A), K_#7.2 (ROW)
unnamed: D9.2 (A), K_#8.2 (ROW)
unnamed: D10.2 (A), K_#9.2 (ROW)
unnamed: D11.2 (A), K_#0_1.2 (ROW)
unnamed: D12.2 (A), K_-1.2 (ROW)
unnamed: D13.2 (A), K_=1.2 (ROW)
unnamed: D14.2 (A), K_DEL1.2 (ROW)
unnamed: D15.2 (A), K_BACK1.2 (ROW), K_BACK2.2 (ROW)
unnamed: D16.2 (A), K_TAB1.2 (ROW)
unnamed: D17.2 (A), K_Q1.2 (ROW)
unnamed: D18.2 (A), K_W1.2 (ROW)
unnamed: D19.2 (A), K_E1.2 (ROW)
unnamed: D20.2 (A), K_R1.2 (ROW)
unnamed: D21.2 (A), K_T1.2 (ROW)
unnamed: D22.2 (A), K_Y1.2 (ROW)
unnamed: D23.2 (A), K_U1.2 (ROW)
unnamed: D24.2 (A), K_I1.2 (ROW)
unnamed: D25.2 (A), K_O1.2 (ROW)
unnamed: D26.2 (A), K_P1.2 (ROW)
unnamed: D27.2 (A), K_[1.2 (ROW)
unnamed: D28.2 (A), K_]1.2 (ROW)
unnamed: D29.2 (A), K_\1.2 (ROW)
unnamed: D30.2 (A), K_CAPS1.2 (ROW), K_CAPS2.1 (COL)
unnamed: D31.2 (A), K_A1.2 (ROW)
unnamed: D32.2 (A), K_S1.2 (ROW)
unnamed: D33.2 (A), K_D1.2 (ROW)
unnamed: D34.2 (A), K_F1.2 (ROW)
unnamed: D35.2 (A), K_G1.2 (ROW)
unnamed: D36.2 (A), K_H1.2 (ROW)
unnamed: D37.2 (A), K_J1.2 (ROW)
unnamed: D38.2 (A), K_K1.2 (ROW)
unnamed: D39.2 (A), K_L1.2 (ROW)
unnamed: D40.2 (A), K_;1.2 (ROW)
unnamed: D41.2 (A), K_'1.2 (ROW)
unnamed: D42.2 (A), K_EX1.2 (ROW)
unnamed: D43.2 (A), K_ENTER1.2 (ROW)
unnamed: D44.2 (A), K_SHIFT1.2 (ROW)
unnamed: D45.2 (A), K_EX2.2 (ROW)
unnamed: D46.2 (A), K_Z1.2 (ROW)
unnamed: D47.2 (A), K_X1.2 (ROW)
unnamed: D48.2 (A), K_C1.2 (ROW)
unnamed: D49.2 (A), K_V1.2 (ROW)
unnamed: D50.2 (A), K_B1.2 (ROW)
unnamed: D51.2 (A), K_N1.2 (ROW)
unnamed: D52.2 (A), K_M1.2 (ROW)
unnamed: D53.2 (A), K_,1.2 (ROW)
unnamed: D54.2 (A), K_.1.2 (ROW)
unnamed: D55.2 (A), K_EX3.2 (ROW)
unnamed: D56.2 (A), K_/1.2 (ROW)
unnamed: D57.2 (A), K_SHIFT2.2 (ROW)
unnamed: D58.2 (A), K_UP1.2 (ROW)
unnamed: D59.2 (A), K_EX4.2 (ROW)
unnamed: D60.2 (A), K_LEFT1.2 (ROW)
unnamed: D61.2 (A), K_DOWN1.2 (ROW)
unnamed: D62.2 (A), K_RIGHT1.2 (ROW)
ROW0: D1.1 (K), D2.1 (K), D3.1 (K), D4.1 (K), D5.1 (K), D6.1 (K), D7.1 (K), D8.1 (K), D9.1 (K), D10.1 (K), D11.1 (K), D12.1 (K), D13.1 (K), D14.1 (K), D15.1 (K), D42.1 (K); also elsewhere on the board
ROW1: D16.1 (K), D17.1 (K), D18.1 (K), D19.1 (K), D20.1 (K), D21.1 (K), D22.1 (K), D23.1 (K), D24.1 (K), D25.1 (K), D26.1 (K), D27.1 (K), D28.1 (K), D29.1 (K), D45.1 (K); also elsewhere on the board
ROW2: D30.1 (K), D31.1 (K), D32.1 (K), D33.1 (K), D34.1 (K), D35.1 (K), D36.1 (K), D37.1 (K), D38.1 (K), D39.1 (K), D40.1 (K), D41.1 (K), D43.1 (K), D55.1 (K); also elsewhere on the board
ROW3: D44.1 (K), D46.1 (K), D47.1 (K), D48.1 (K), D49.1 (K), D50.1 (K), D51.1 (K), D52.1 (K), D53.1 (K), D54.1 (K), D56.1 (K), D57.1 (K), D58.1 (K), D59.1 (K); also elsewhere on the board
ROW4: D60.1 (K), D61.1 (K), D62.1 (K); also elsewhere on the board

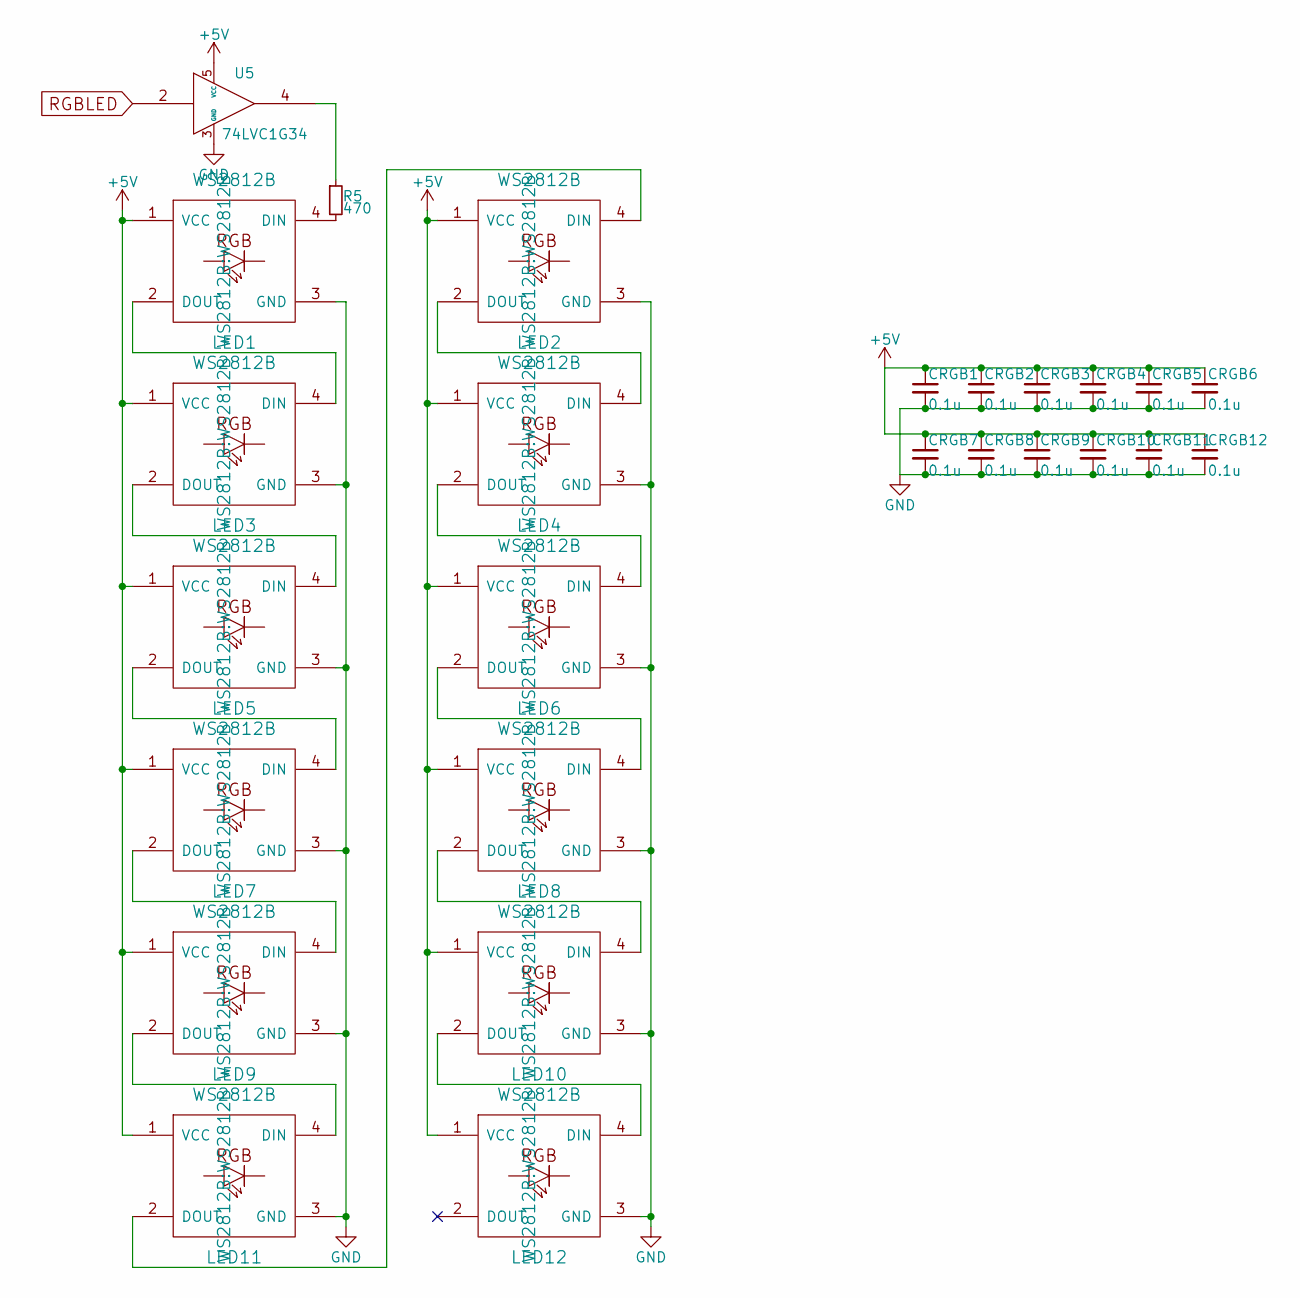
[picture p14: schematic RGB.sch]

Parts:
CRGB1, CRGB2, CRGB3, CRGB4, CRGB5, CRGB6, CRGB7, CRGB8, CRGB9, CRGB10, CRGB11, CRGB12: 0.1u; C_0603
LED1, LED2, LED3, LED4, LED5, LED6, LED7, LED8, LED9, LED10, LED11, LED12: WS2812B
R5: 470; R_0603
U5: 74LVC1G34; SOT-353_SC-70-5

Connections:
+5V: CRGB1.1, CRGB2.1, CRGB3.1, CRGB4.1, CRGB5.1, CRGB6.1, CRGB7.1, CRGB8.1, CRGB9.1, CRGB10.1, CRGB11.1, CRGB12.1, LED1.1 (VCC), LED2.1 (VCC), LED3.1 (VCC), LED4.1 (VCC), LED5.1 (VCC), LED6.1 (VCC), LED7.1 (VCC), LED8.1 (VCC), LED9.1 (VCC), LED10.1 (VCC), LED11.1 (VCC), LED12.1 (VCC), U5.5 (VCC); also elsewhere on the board
GND: CRGB1.2, CRGB2.2, CRGB3.2, CRGB4.2, CRGB5.2, CRGB6.2, CRGB7.2, CRGB8.2, CRGB9.2, CRGB10.2, CRGB11.2, CRGB12.2, LED1.3 (GND), LED2.3 (GND), LED3.3 (GND), LED4.3 (GND), LED5.3 (GND), LED6.3 (GND), LED7.3 (GND), LED8.3 (GND), LED9.3 (GND), LED10.3 (GND), LED11.3 (GND), LED12.3 (GND), U5.3 (GND); also elsewhere on the board
unnamed: LED1.2 (DOUT), LED3.4 (DIN)
unnamed: LED1.4 (DIN), R5.2
unnamed: LED2.2 (DOUT), LED4.4 (DIN)
unnamed: LED3.2 (DOUT), LED5.4 (DIN)
unnamed: LED4.2 (DOUT), LED6.4 (DIN)
unnamed: LED5.2 (DOUT), LED7.4 (DIN)
unnamed: LED6.2 (DOUT), LED8.4 (DIN)
unnamed: LED7.2 (DOUT), LED9.4 (DIN)
unnamed: LED10.2 (DOUT), LED12.4 (DIN)
unnamed: LED8.2 (DOUT), LED10.4 (DIN)
unnamed: LED2.4 (DIN), LED11.2 (DOUT)
unnamed: LED9.2 (DOUT), LED11.4 (DIN)
unnamed: R5.1, U5.4
RGBLED: U5.2; also elsewhere on the board

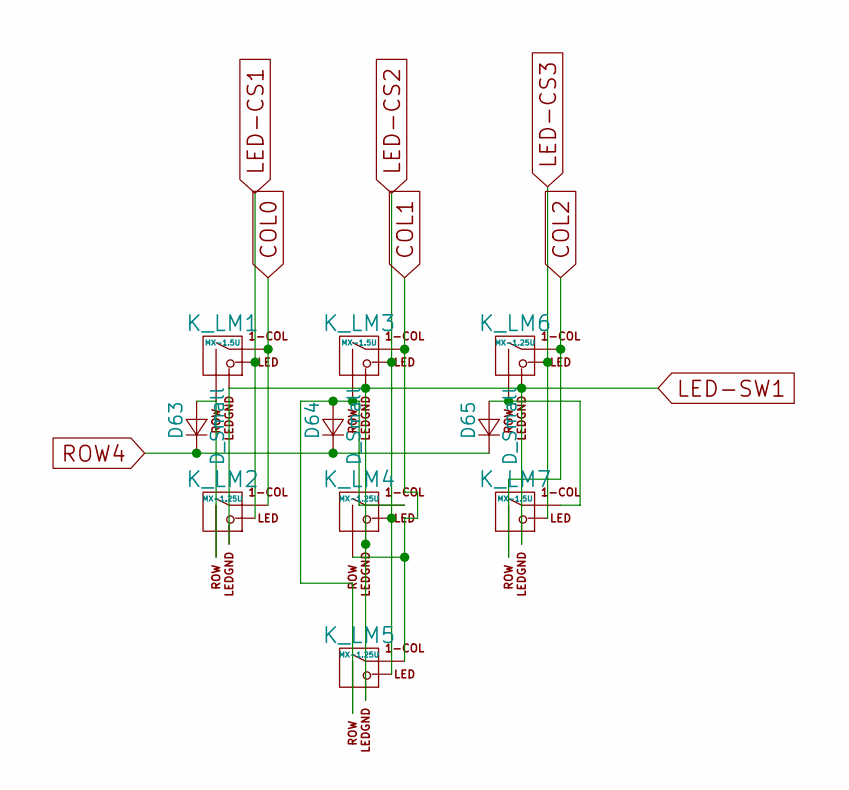
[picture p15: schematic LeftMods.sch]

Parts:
D63, D64, D65: D_Small; D_SOD-123
K_LM1, K_LM7: MX-1.5U
K_LM2, K_LM4: MX-1.25U; MX-1.25U-FLIPPED
K_LM3: MX-1.5U; MX-1.5U-FLIPPED
K_LM5, K_LM6: MX-1.25U

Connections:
COL0: K_LM1.1 (COL), K_LM2.1 (COL); also elsewhere on the board
COL1: K_LM3.1 (COL), K_LM4.2 (ROW), K_LM5.1 (COL); also elsewhere on the board
COL2: K_LM6.1 (COL), K_LM7.2 (ROW); also elsewhere on the board
LED-CS1: K_LM1.3 (LED), K_LM2.3 (LED); also elsewhere on the board
LED-CS2: K_LM3.3 (LED), K_LM4.3 (LED), K_LM5.3 (LED); also elsewhere on the board
LED-CS3: K_LM6.3 (LED), K_LM7.3 (LED); also elsewhere on the board
LED-SW1: K_LM1.4 (LEDGND), K_LM2.4 (LEDGND), K_LM3.4 (LEDGND), K_LM4.4 (LEDGND), K_LM5.4 (LEDGND), K_LM6.4 (LEDGND), K_LM7.4 (LEDGND); also elsewhere on the board
unnamed: D63.2 (A), K_LM1.2 (ROW), K_LM2.2 (ROW)
unnamed: D64.2 (A), K_LM3.2 (ROW), K_LM4.1 (COL), K_LM5.2 (ROW)
unnamed: D65.2 (A), K_LM6.2 (ROW), K_LM7.1 (COL)
ROW4: D63.1 (K), D64.1 (K), D65.1 (K); also elsewhere on the board

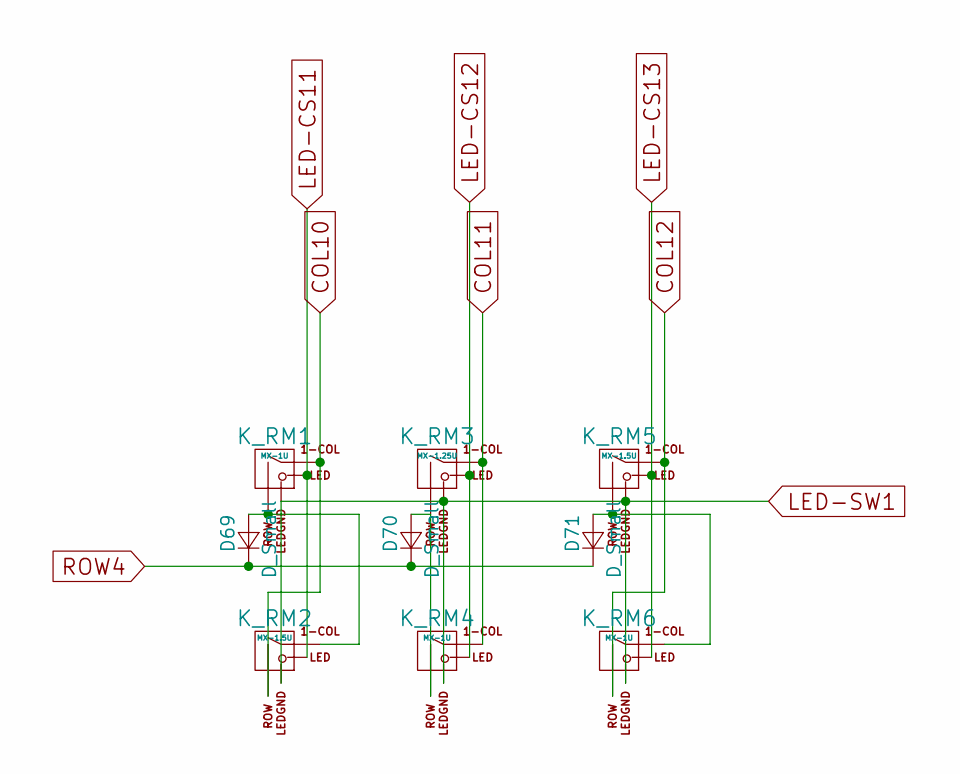
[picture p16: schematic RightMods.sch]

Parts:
D69, D70, D71: D_Small; D_SOD-123
K_RM1: MX-1U
K_RM2: MX-1.5U; MX-1.5U-FLIPPED
K_RM3: MX-1.25U
K_RM4, K_RM6: MX-1U; MX-1U-FLIPPED
K_RM5: MX-1.5U

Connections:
COL10: K_RM1.1 (COL), K_RM2.2 (ROW); also elsewhere on the board
COL11: K_RM3.1 (COL), K_RM4.1 (COL); also elsewhere on the board
COL12: K_RM5.1 (COL), K_RM6.2 (ROW); also elsewhere on the board
LED-CS11: K_RM1.3 (LED), K_RM2.3 (LED); also elsewhere on the board
LED-CS12: K_RM3.3 (LED), K_RM4.3 (LED); also elsewhere on the board
LED-CS13: K_RM5.3 (LED), K_RM6.3 (LED); also elsewhere on the board
LED-SW1: K_RM1.4 (LEDGND), K_RM2.4 (LEDGND), K_RM3.4 (LEDGND), K_RM4.4 (LEDGND), K_RM5.4 (LEDGND), K_RM6.4 (LEDGND); also elsewhere on the board
unnamed: D69.2 (A), K_RM1.2 (ROW), K_RM2.1 (COL)
unnamed: D70.2 (A), K_RM3.2 (ROW), K_RM4.2 (ROW)
unnamed: D71.2 (A), K_RM5.2 (ROW), K_RM6.1 (COL)
ROW4: D69.1 (K), D70.1 (K), D71.1 (K); also elsewhere on the board

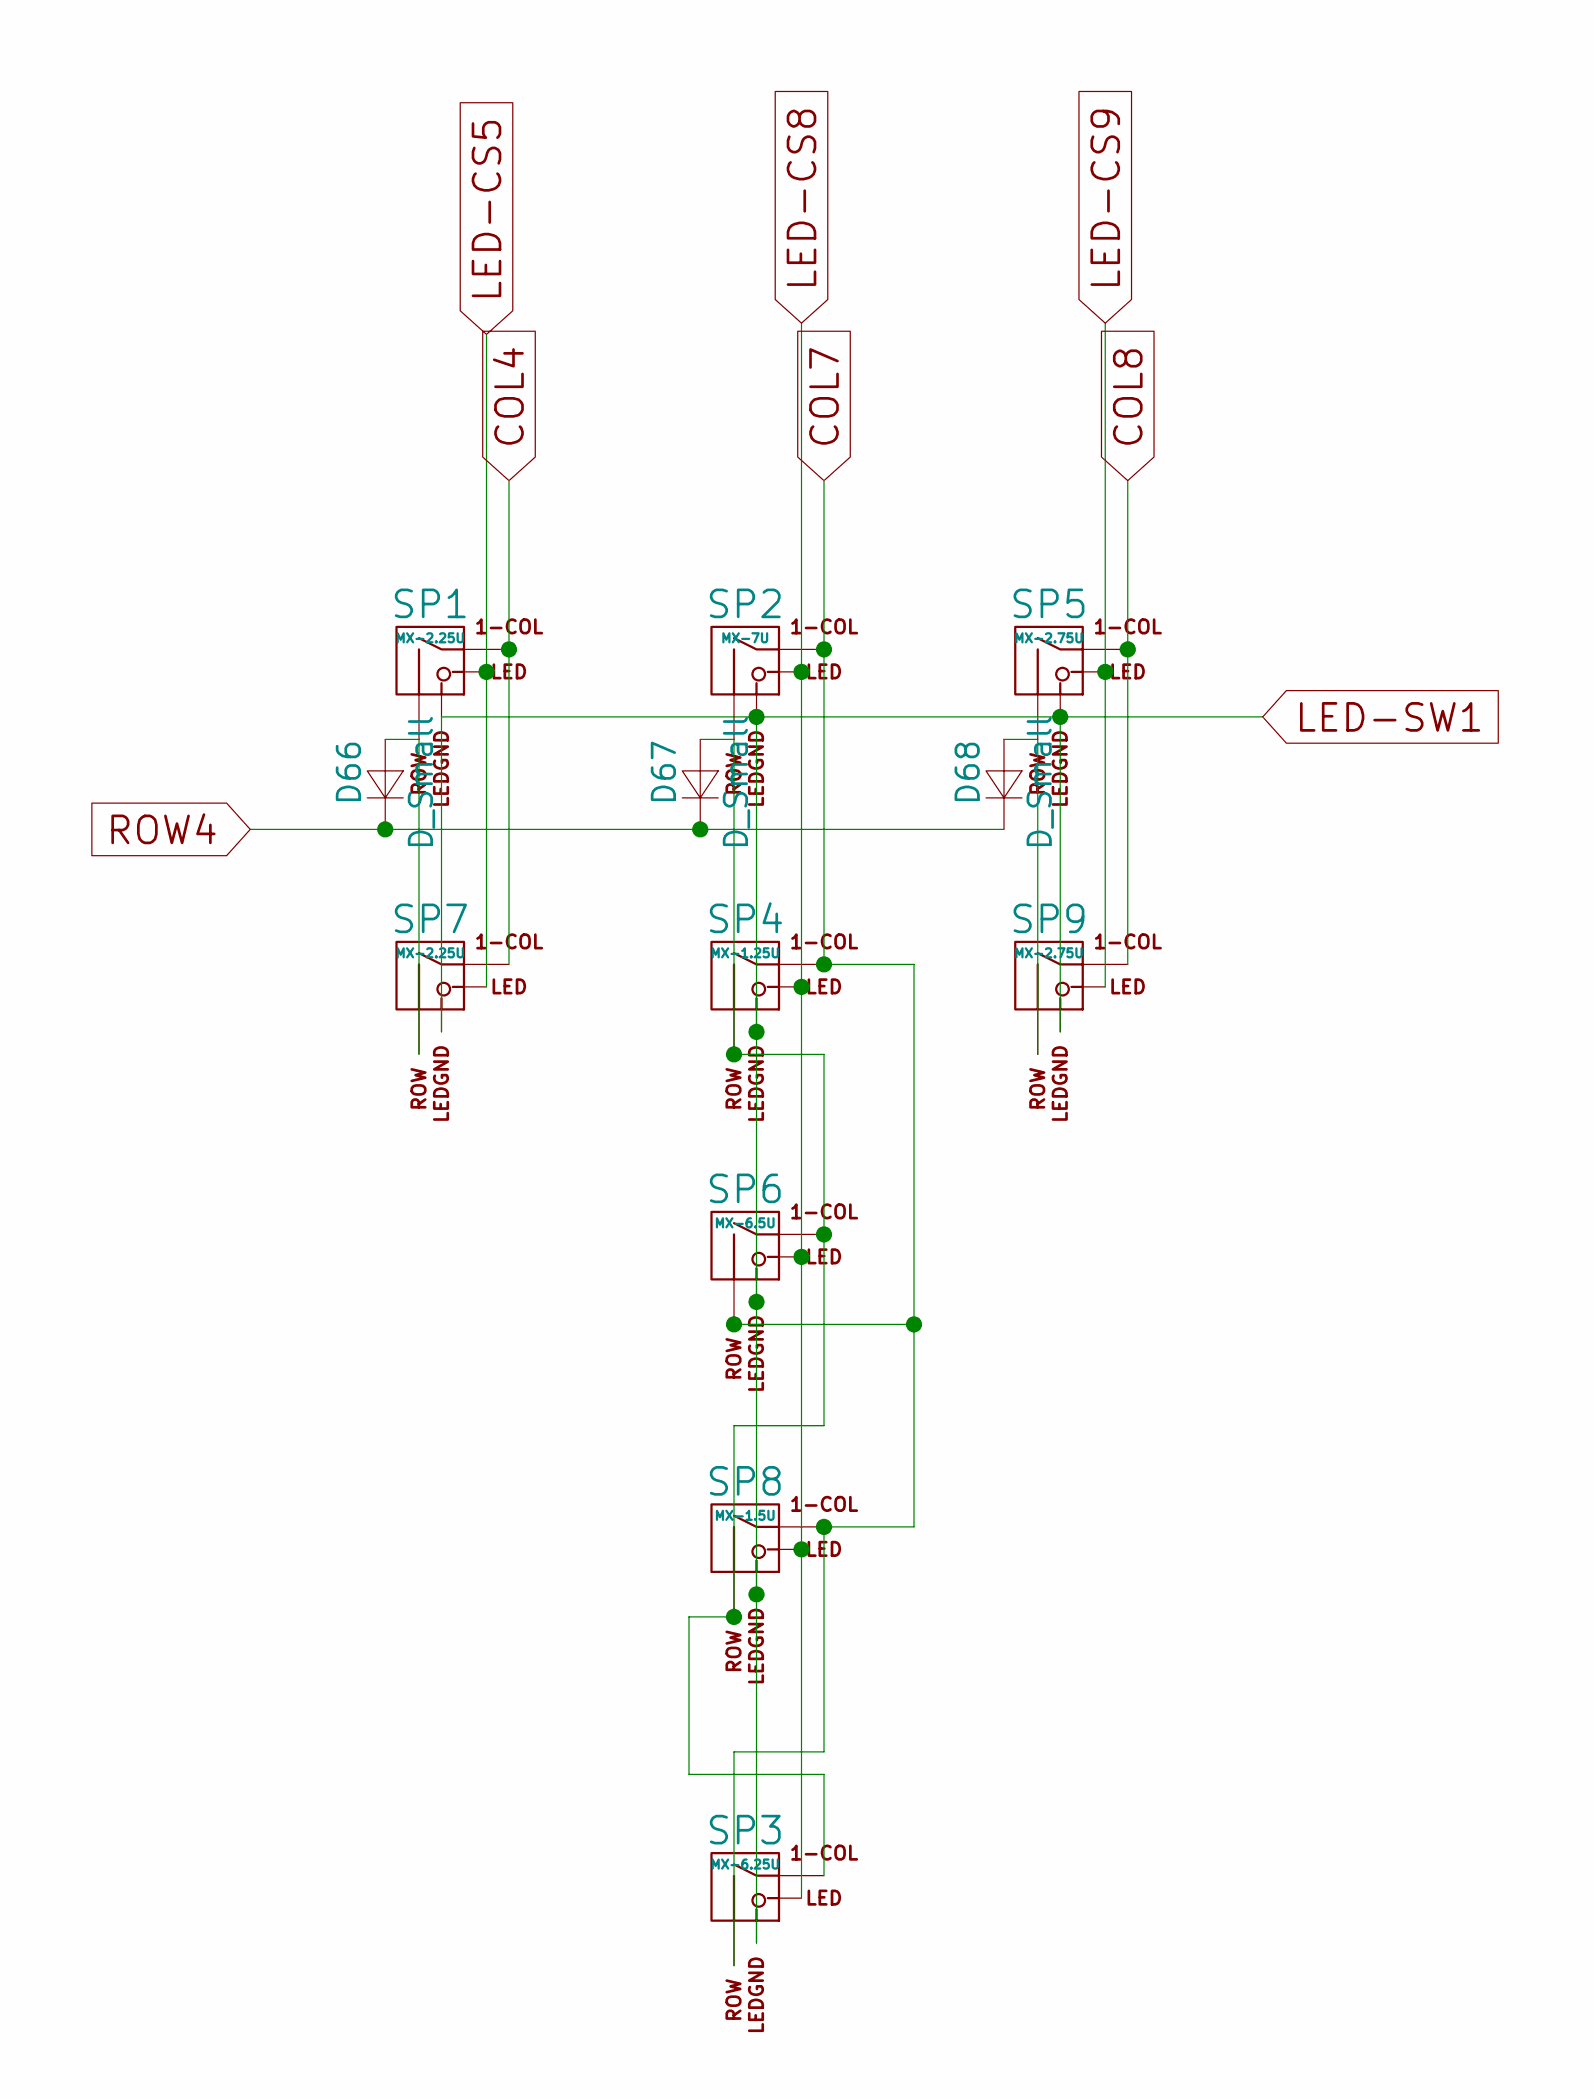
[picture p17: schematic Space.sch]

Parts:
D66, D67, D68: D_Small; D_SOD-123
SP1, SP7: MX-2.25U; MX-2.25U-ReversedStabilizers
SP2: MX-7U; MX-7U-ReversedStabilizers
SP3: MX-6.25U; MX-6.25U-ReversedStabilizers
SP4: MX-1.25U; MX-1.25U-FLIPPED
SP5, SP9: MX-2.75U; MX-2.75U-ReversedStabilizers
SP6: MX-6.5U; MX-6.5U-FLIPPED-ReversedStabilizers
SP8: MX-1.5U

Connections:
COL4: SP1.1 (COL), SP7.1 (COL); also elsewhere on the board
COL7: SP2.1 (COL), SP3.2 (ROW), SP4.1 (COL), SP6.2 (ROW), SP8.1 (COL); also elsewhere on the board
COL8: SP5.1 (COL), SP9.1 (COL); also elsewhere on the board
LED-CS5: SP1.3 (LED), SP7.3 (LED); also elsewhere on the board
LED-CS8: SP2.3 (LED), SP3.3 (LED), SP4.3 (LED), SP6.3 (LED), SP8.3 (LED); also elsewhere on the board
LED-CS9: SP5.3 (LED), SP9.3 (LED); also elsewhere on the board
LED-SW1: SP1.4 (LEDGND), SP2.4 (LEDGND), SP3.4 (LEDGND), SP4.4 (LEDGND), SP5.4 (LEDGND), SP6.4 (LEDGND), SP7.4 (LEDGND), SP8.4 (LEDGND), SP9.4 (LEDGND); also elsewhere on the board
unnamed: D66.2 (A), SP1.2 (ROW), SP7.2 (ROW)
unnamed: D67.2 (A), SP2.2 (ROW), SP3.1 (COL), SP4.2 (ROW), SP6.1 (COL), SP8.2 (ROW)
unnamed: D68.2 (A), SP5.2 (ROW), SP9.2 (ROW)
ROW4: D66.1 (K), D67.1 (K), D68.1 (K); also elsewhere on the board

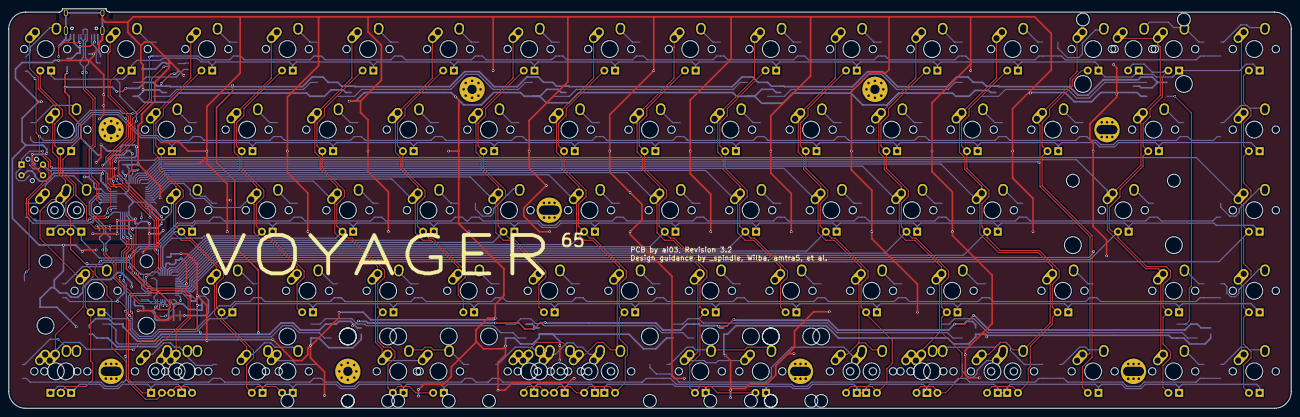
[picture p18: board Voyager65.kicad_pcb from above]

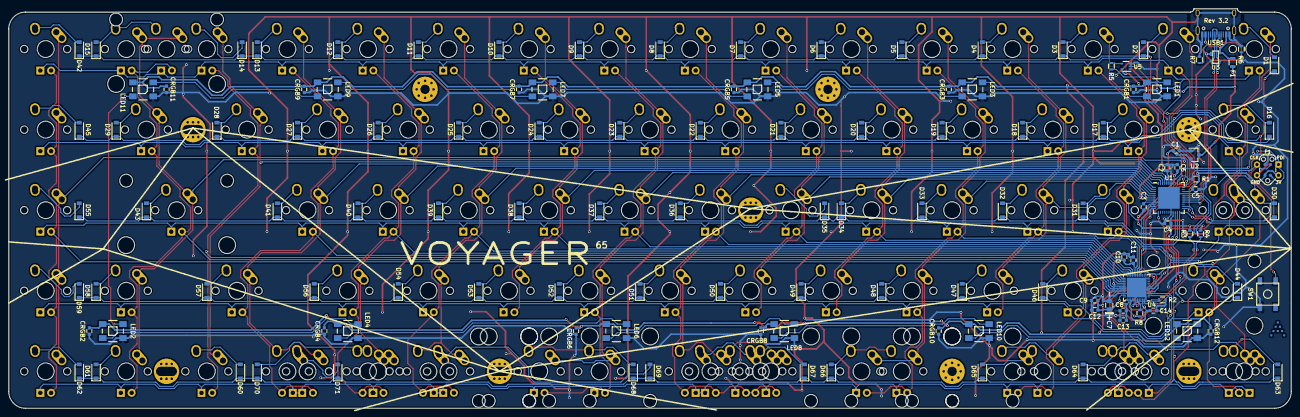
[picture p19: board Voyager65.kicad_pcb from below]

Board: 2 copper layers, 303.2 x 94.5 mm, 212 parts (126 on the bottom side), 142 nets.

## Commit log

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2018-01-19 Begin building schematic, bit by bit
    [_saved_VoyagerII.sch]
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2018-01-20 Tune up controller to final state
    [VoyagerII.sch]
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2018-01-20 Change PCB sheet size
    [VoyagerII.kicad_pcb]
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2018-01-20 Sort parts on PCB
    [VoyagerII.kicad_pcb]
2018-01-20 Roughly break out controller
    [VoyagerII.kicad_pcb]
2018-01-21 Place down some matrix stuff
    [Matrix.sch, VoyagerII.sch]
2018-01-21 Create IS31FL3731-SALS2 schem module
    [VoyagerII.sch]
2018-01-21 Wire the LED controller
    [VoyagerII.sch]
2018-01-21 Add LED matrix labels
    [VoyagerII.sch]
2018-01-21 Label row 1 of switches
    [Matrix.sch]
2018-01-21 Continue labeling and adding keys on matrix
    [Matrix.sch]
2018-01-22 Build right shift in separate sheet
    [Matrix.sch, RightShift.sch, VoyagerII.sch]
2018-01-22 Break matrix up into multiple sheets
    [LeftMods.sch, Matrix.sch, RightMods.sch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]
2018-01-22 Assign footprints, along with placeholders for mx
    [LeftMods.sch, Matrix.sch, RightMods.sch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]
2018-01-22 Repair footprints on main matrix sheet
    [Matrix.sch]
2018-01-22 Repair all mx footprints
    [LeftMods.sch, RightMods.sch]
2018-01-22 Start placing some footprints
    [VoyagerII.kicad_pcb]
2018-01-22 Fix backspace, finish row 1
    [Matrix.sch, VoyagerII.kicad_pcb]
2018-01-22 Dislodge PTC for routing
    [VoyagerII.kicad_pcb]
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2018-01-22 Layout broken out bottom row
    [VoyagerII.kicad_pcb]
2018-01-22 Fix right shift sizes
    [RightShift.sch]
2018-01-22 Combine and place right shift cluster
    [VoyagerII.kicad_pcb]
2018-01-22 Combine and position bottom row
    [VoyagerII.kicad_pcb]
2018-01-22 Swap alps row for alps-only fp
    [LeftMods.sch, RightMods.sch]
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2018-01-22 Fix USB net name
    [VoyagerII.kicad_pcb, VoyagerII.sch]
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2018-01-22 Break out controller a bit
    [VoyagerII.kicad_pcb, VoyagerII.sch]
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2018-01-22 Update breakout for RGB placement
    [VoyagerII.kicad_pcb]
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2018-01-22 Repair bottom row after refractor]
    [VoyagerII.kicad_pcb]
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2018-01-22 Fix LED MCU breakout
    [VoyagerII.kicad_pcb]
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2018-01-22 Rename I2C net for easier routing
    [VoyagerII.sch]
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2018-01-23 Forgot one col, fix
    [VoyagerII.kicad_pcb]
2018-01-23 Wire and name rows
    [Matrix.sch]
2018-01-23 Place diodes, remove duplicates
    [LeftMods.sch, Matrix.sch, RightMods.sch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]
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2018-01-23 Begin connecting diodes to switches
    [VoyagerII.kicad_pcb]
2018-01-23 Connect up more diodes
    [VoyagerII.kicad_pcb]
2018-01-23 Fix incorrect spacebar pinout
    [Matrix.sch]
2018-01-23 Route a few RGBs
    [VoyagerII.kicad_pcb]
2018-01-23 Add 500 ohm resistor inline to RGB data
    [RGB.sch, VoyagerII.sch]
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2018-01-24 Add basic row col to subsheets
    [LeftMods.sch, RightMods.sch, RightShift.sch]
2018-01-25 Begin fixing rshift pinout
    [RightShift.sch, VoyagerII.kicad_pcb]
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2018-01-25 Wire more compat footprints
    [Matrix.sch, VoyagerII.kicad_pcb]
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2018-01-25 Fill controller gnd plane
    [VoyagerII.kicad_pcb]
2018-01-25 Continue routing without LED
    [VoyagerII.kicad_pcb]
2018-01-25 Route all except controller 5v rail
    [VoyagerII.kicad_pcb]
2018-01-25 Tune trace busses to take less space
    [VoyagerII.kicad_pcb]
2018-01-26 Begin routing LED rows
    [Matrix.sch]
2018-01-28 Route left half LED rows
    [LeftMods.sch, Matrix.sch]
2018-01-28 Temporary progress save, end of branch for now
    [VoyagerII.kicad_pcb]
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2018-01-28 Unroute and reposition PCB
    [VoyagerII.kicad_pcb]
2018-01-28 Swap footprints for No-LED counterparts
    [LeftMods.sch, Matrix.sch, RightMods.sch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]
2018-01-28 Begin creating LED matrix
    [LEDMatrix.sch, LeftMods.sch, Matrix.sch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]
2018-01-28 Place and annotate LED schematic components
    [LEDMatrix.sch, RGB.sch, VoyagerII.sch]
2018-01-28 Wire lefthand matrix schematic
    [LEDMatrix.sch]
2018-01-28 Join '\' key and ISO '~' key together to save diode
    [Matrix.sch]
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2018-01-28 Place some of the LED footprints
    [VoyagerII.kicad_pcb]
2018-01-28 Prepare for adding more footprints
    [VoyagerII.kicad_pcb]
2018-01-28 Add lefthand compat LEDs
    [LEDMatrix.sch]
2018-01-28 Load and position extra LEDs for lefthand
    [VoyagerII.kicad_pcb]
2018-01-28 Fix LED quantity for enter
    [LEDMatrix.sch, VoyagerII.kicad_pcb]
2018-01-28 Place righthand LED footprints
    [VoyagerII.kicad_pcb]
2018-01-28 Add missing shift-row footprints
    [LEDMatrix.sch, VoyagerII.kicad_pcb]
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2018-01-28 Nudge some parts around
    [VoyagerII.kicad_pcb]
2018-01-28 Route lefthand LED matrix
    [VoyagerII.kicad_pcb]
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2018-01-28 Tune up LED tracks
    [VoyagerII.kicad_pcb]
2018-01-28 Begin routing switch matrix
    [VoyagerII.kicad_pcb]
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2018-01-28 Route most of matrix
    [VoyagerII.kicad_pcb]
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2018-01-29 Add logic schem module
    [VoyagerII.kicad_pcb]
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2018-01-29 Flow more gnd plane, fix i2c voltage
    [VoyagerII.kicad_pcb, VoyagerII.sch]
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2018-01-29 Fix RGB voltage
    [LEDMatrix.sch, LeftMods.sch, Matrix.sch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]
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2018-01-29 Tune up some more traces
    [VoyagerII.kicad_pcb]
2018-01-29 Add in missing backspace stabs
    [Matrix.sch, VoyagerII.kicad_pcb]
2018-01-29 Fix traces to match stabilizer holes
    [VoyagerII.kicad_pcb]
2018-01-29 Replace PTC fuse for 0805
    [VoyagerII.kicad_pcb, VoyagerII.sch]
2018-01-29 Replace PTC footprint on PCB
    [VoyagerII.kicad_pcb]
2018-01-29 Swap ESD protection chip
    [VoyagerII.sch]
2018-01-30 Assign ESD protection chip footprint
    [VoyagerII.sch]
2018-01-30 Replace and reroute ESD chip
    [VoyagerII.kicad_pcb]
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2018-01-30 Improve USB isolation further
    [VoyagerII.kicad_pcb]
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2018-01-30 Move silkscreen labels to legible locations
    [VoyagerII.kicad_pcb]
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2018-01-30 Add some silkscreen art
    [VoyagerII.kicad_pcb]
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2018-01-30 Redo gnd planes, add via fence near controller
    [VoyagerII.kicad_pcb]
2018-01-30 Finish silkscreen and decorations
    [VoyagerII.kicad_pcb]
2018-01-30 Add some stuff to silkscreen
    [VoyagerII.kicad_pcb]
2018-01-30 Add revision text and create final gerbers
    [VoyagerII-B.Cu.gbl, VoyagerII-B.Mask.gbs, VoyagerII-B.SilkS.gbo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]
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2018-02-05 Change and update leftmods
    [LeftMods.sch]
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2018-02-05 Assign footprints to updated mods
    [RightMods.sch]
2018-02-05 Breakout and place switches
    [VoyagerII.kicad_pcb]
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2018-02-09 Replace USB connector
    [LEDMatrix.sch, LeftMods.sch, Matrix.sch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]
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2018-02-10 Replace outline, rereoute some controller traces
    [VoyagerII.kicad_pcb]
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2018-02-10 Tune component labels
    Horizontal for system, vertical for matrix
    [VoyagerII.kicad_pcb]
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2018-03-05 Unroute, prepare for LED chip replacement
    [VoyagerII.kicad_pcb]
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2018-03-05 Revert wireless functionality
    Not this time.
    [VoyagerII.sch]
2018-03-06 Swap LED controller for IS31FL3733
    [RGB.sch, VoyagerII.sch]
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2018-03-06 Revert LED structure
    [LEDMatrix.sch, LeftMods.sch, Matrix.sch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]
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2018-03-06 Replace and route bus
    [VoyagerII.kicad_pcb]
2018-03-06 Fix spacebar LED
    [Matrix.sch, RightShift.sch, VoyagerII.kicad_pcb]
2018-03-06 Finalize for error checking
    [VoyagerII.kicad_pcb]
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2018-04-11 Replace MCU, route bus
    [LeftMods.sch, Matrix.sch, RightMods.sch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]
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2018-04-12 Replace reset switch
    [Voyager65.kicad_pcb, Voyager65.sch]
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2018-04-19 Very final error check and regen of gerbers
    [Voyager65-B.Cu.gbl, Voyager65-B.Fab.gbr, Voyager65-B.Mask.gbs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]
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2018-04-19 Create plate files with dummy drill files
    Because fab complains
    [Tada68-Alps-B.Cu.gbl, Tada68-Alps-B.Mask.gbs, Tada68-Alps-B.SilkS.gbo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]
2018-04-19 Swap USB back
    [RGB.sch, Tada68-MX.dxf, Voyager65.kicad_pcb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]
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
